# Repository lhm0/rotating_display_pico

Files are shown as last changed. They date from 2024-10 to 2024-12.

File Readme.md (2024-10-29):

# Rotating Display Pico

## Abstract: 
The Rotating Display Pico is a compact disc-sized device that rotates quietly using a CD motor. It features 56 white LEDs which are controlled by a raspberry pi pico. The device can display animated images as well as time and weather data sourced from the internet. It is wirelessly powered and controlled via a user-friendly web interface. The device uses off-the-shelf components and is easy to assemble in a DIY electronics project.
 
<p align="center"> 
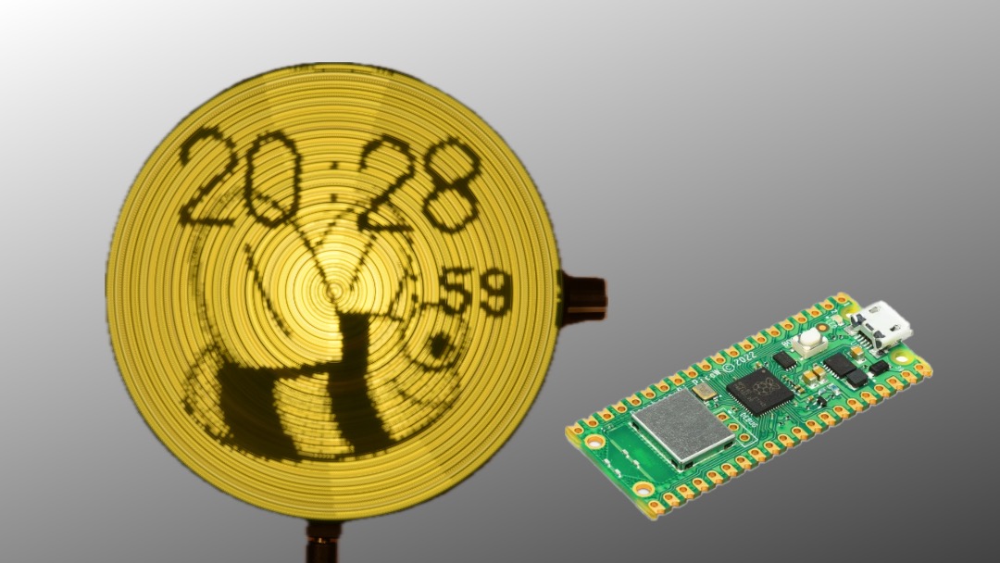
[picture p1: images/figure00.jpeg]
  
</p>

<p align="center"> 
<a href="https://youtu.be/Msv1gF6FXeg" target="_blank">
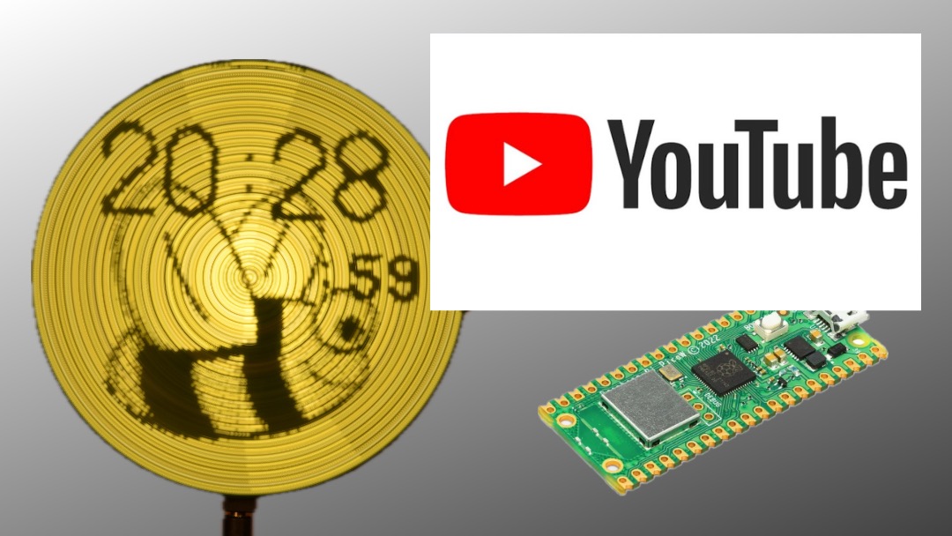
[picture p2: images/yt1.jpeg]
  
</a>
</p> 

## 1. Description of the device

The Rotating Display pico device comprises two primary units: a power supply unit and a display board (**figure 1**). Both are circular in design, with a diameter of 120mm, similar to the dimensions of a standard Compact Disk. The display board is rotated by a CD motor. Energy is wirelessly transmitted from the power supply unit to the display board, eliminating the need for wired connections.

<p align="center"> 
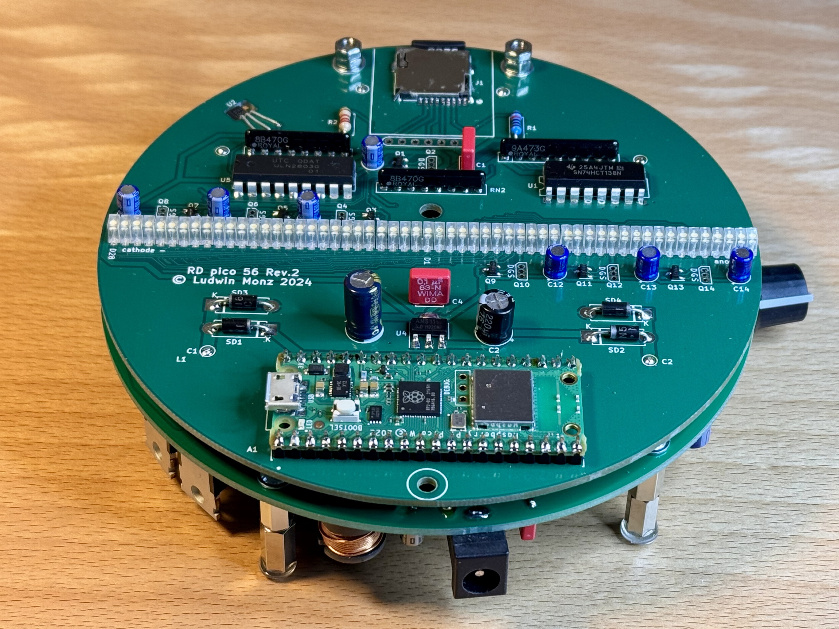
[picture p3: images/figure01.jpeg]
  
</p>

**Figure 1:  Rotating Display pico assembly.** The lower PCB is the power supply with wireless power transmission, the upper PCB is the display board.

The display board is equipped with a row containing 56 white LEDs. The LED operations are controlled by a Raspberry Pi Pico W, which at the same time generates the display content, maintains a Wi-Fi connection to the internet, and provides a web user interface. Images (including animated images) can be stored on and loaded from a micro SMD card. 

This internet connection allows the device to retrieve the time from a time server, ensuring time accuracy. It also allows for the acquisition of weather data. Device operation is managed through a web interface (**figure 2**), accessible from any web browser. The interface allows users to manage login credentials, upload image files to the display, and control image and configuration files through a file manager.

<p align="center"> 
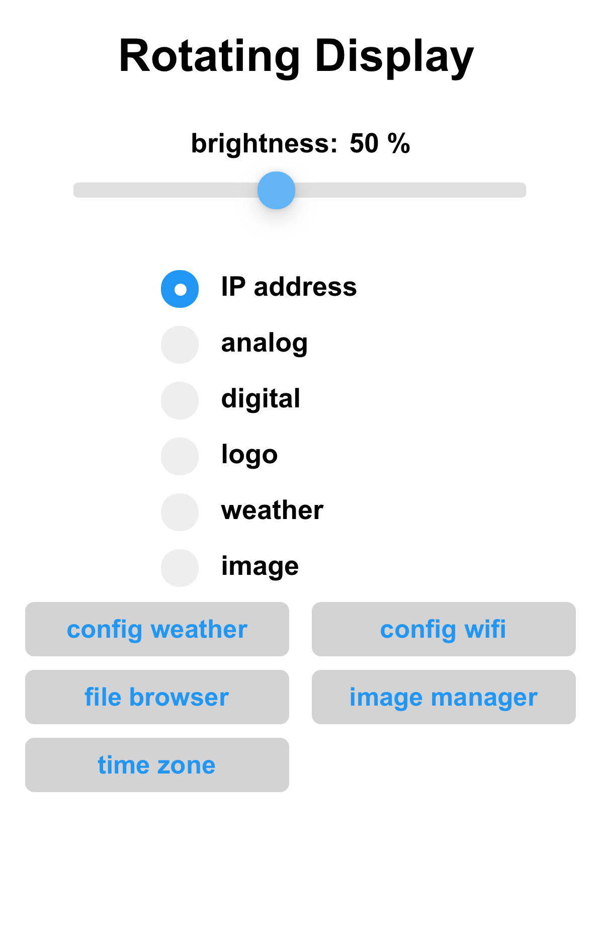
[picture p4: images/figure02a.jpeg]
  
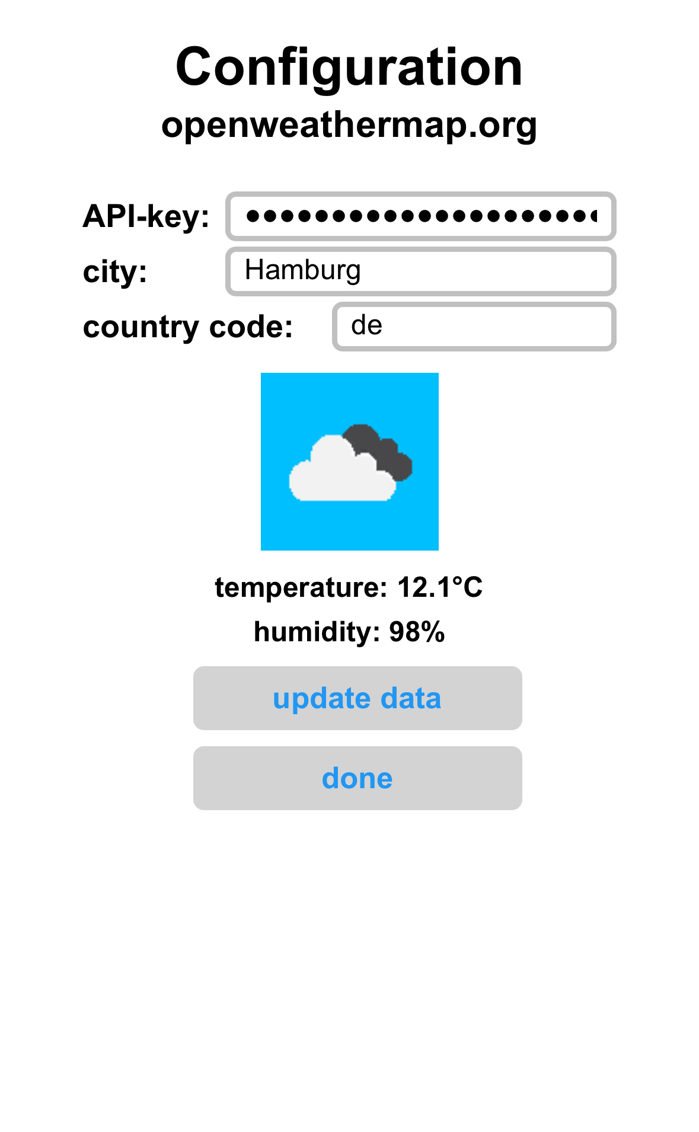
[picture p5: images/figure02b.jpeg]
  
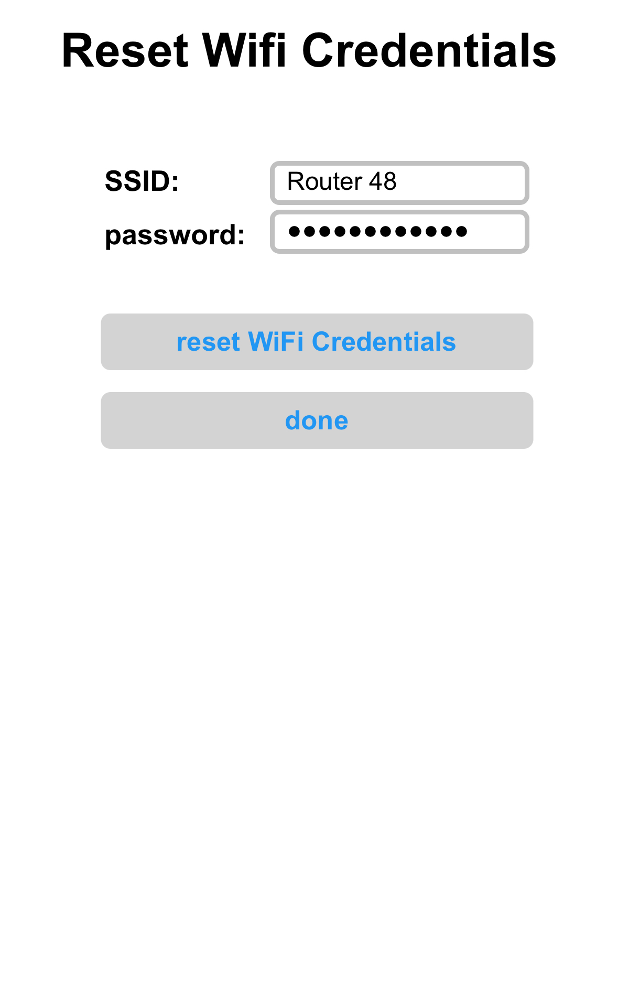
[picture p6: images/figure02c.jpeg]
  
</p>
<p align="center"> 
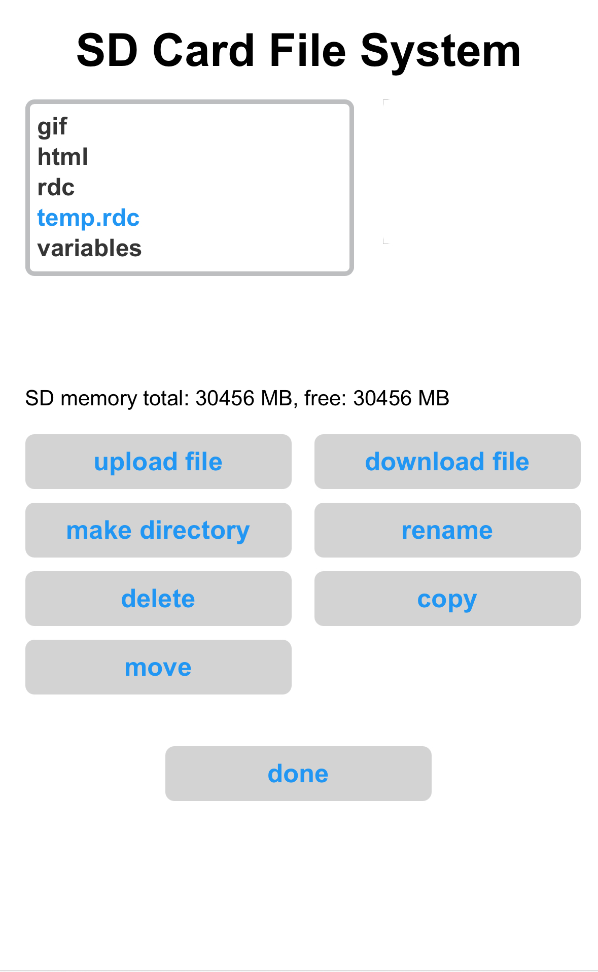
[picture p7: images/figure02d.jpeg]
  
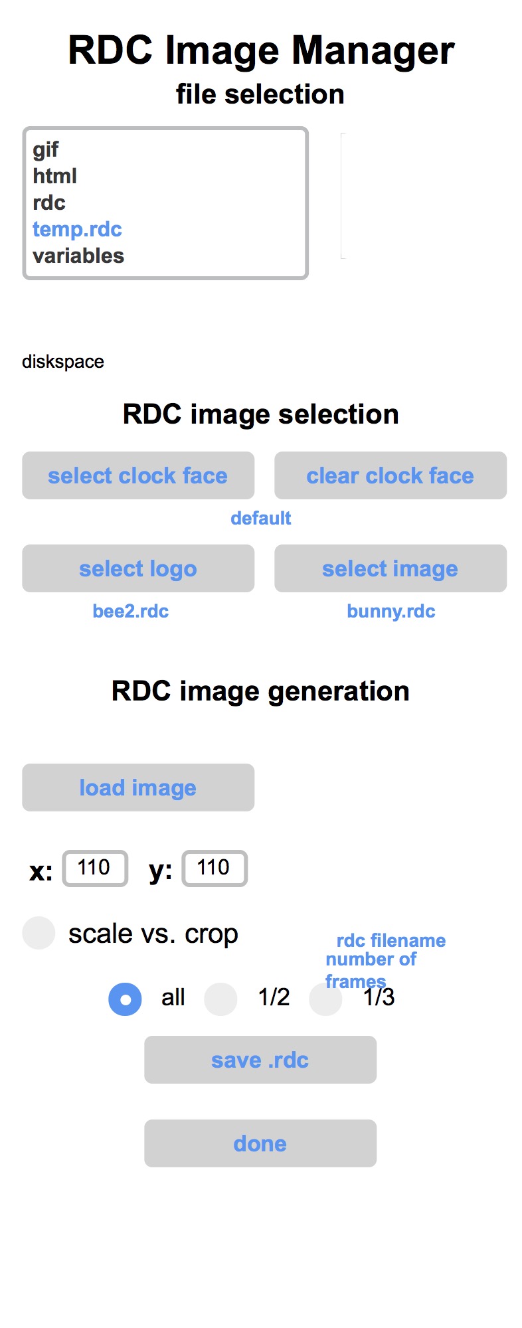
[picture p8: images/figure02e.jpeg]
  
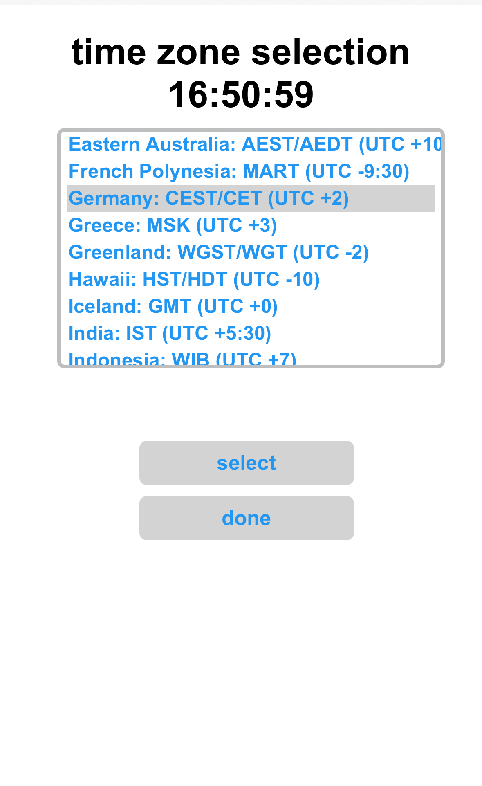
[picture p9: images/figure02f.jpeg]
  
</p>

**Figure 2:** The **web user interface** allows for operating mode selection and device configuration.

## 2. Operating modes

When switched on, the device tries to connect to a known wifi. If no valid wifi credentials are found, the unit will be configured as wifi access point. In this mode, a computer or mobile device can be connected, directly (SSID: RD56m, no password). 

Once the wifi connection has been established, the unit will display its IP address on the  home page of the device (**figure 3**). Enter this address in your web browser. This will load the web user interface and will allow you to configure your local wifi.

<p align="center"> 
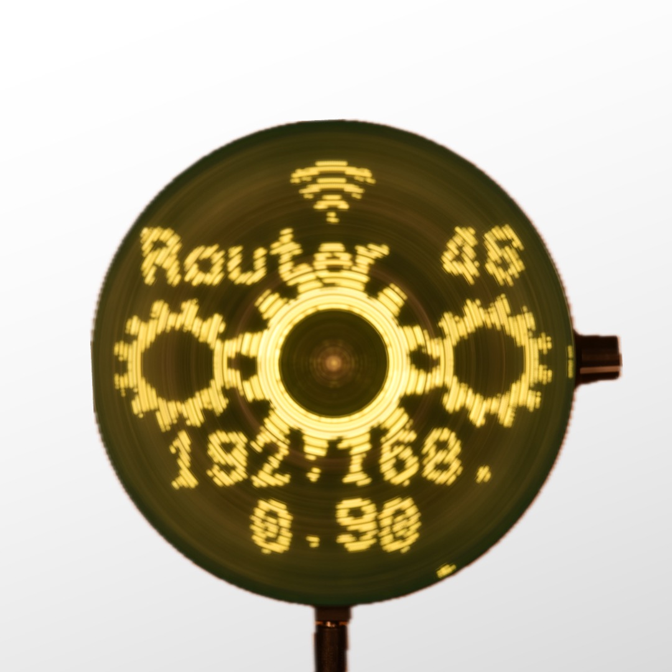
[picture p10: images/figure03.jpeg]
  
</p>

**Figure 3: home page.**

There are several operating modes that display time and weather information (**figure 4**). The logo clock mode integrates a customizable image into the clock face. The image can be easily uploaded from the user interface. The same is true for the analog clock, which uses a customizable clock face in the background.

<p align="center"> 
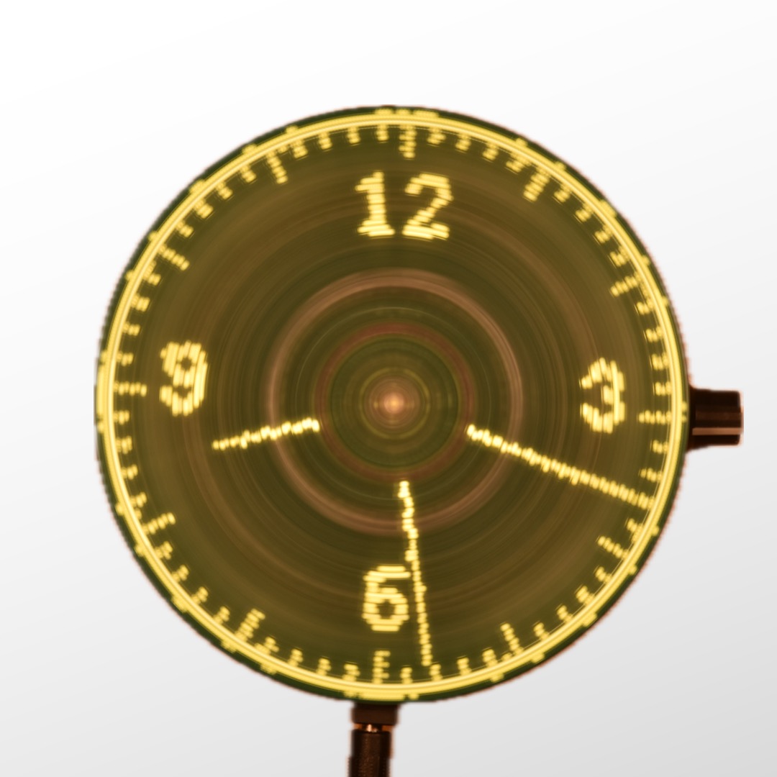
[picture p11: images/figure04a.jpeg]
  
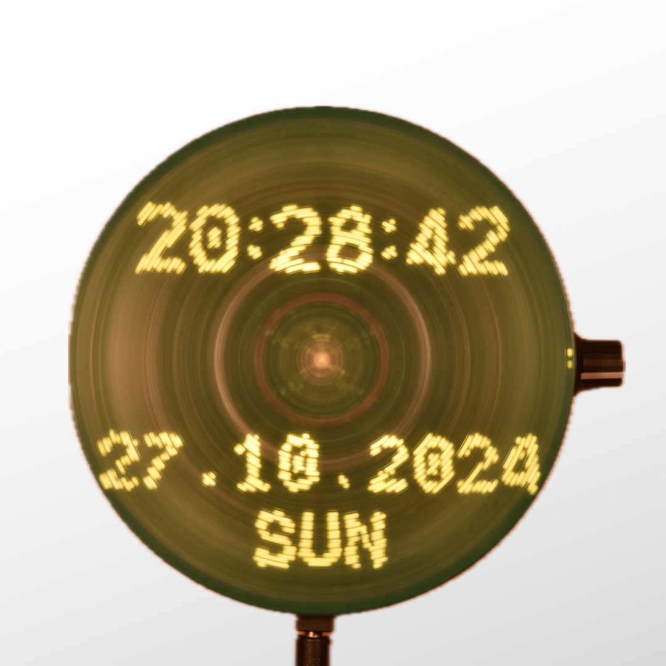
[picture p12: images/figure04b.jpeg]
  
</p>
<p align="center"> 
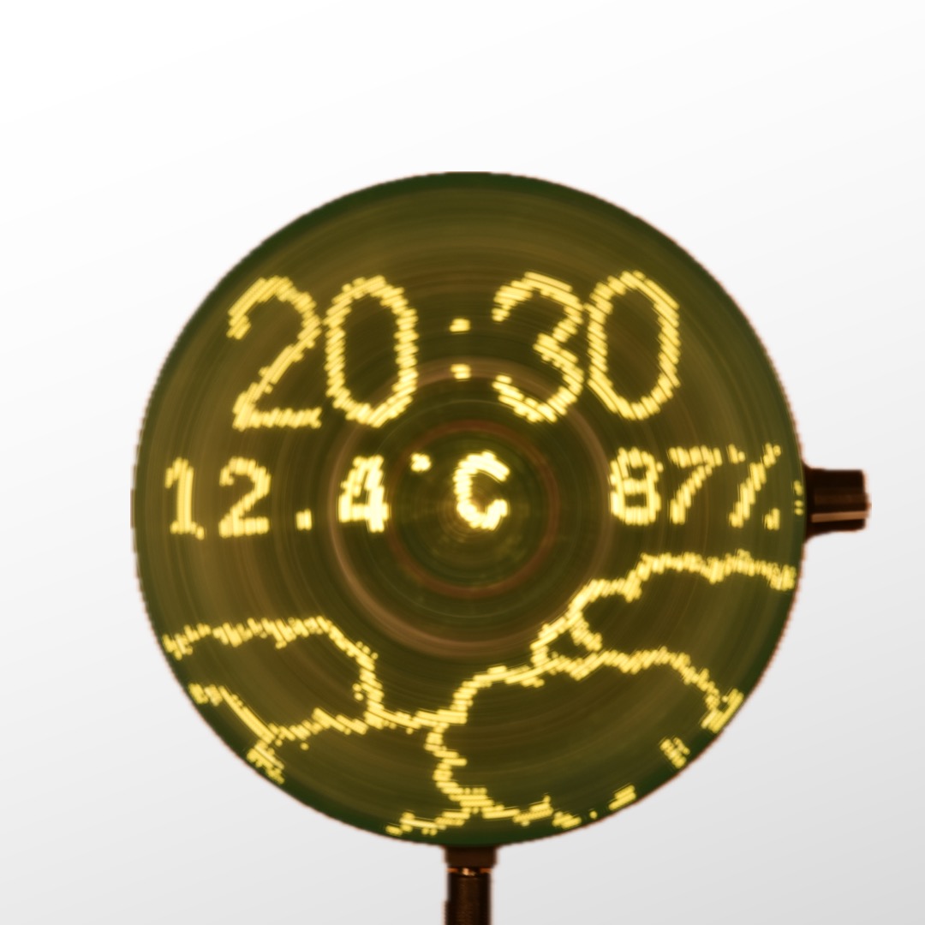
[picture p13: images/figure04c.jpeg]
  
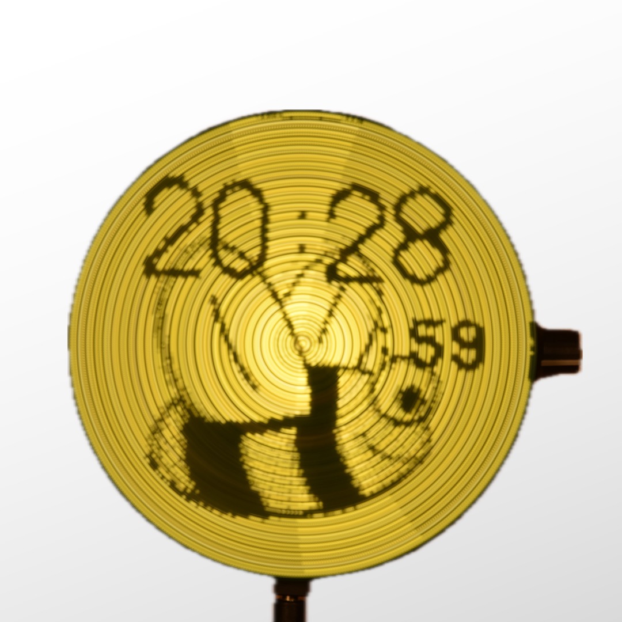
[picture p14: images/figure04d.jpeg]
  
</p>
<p align="center"> 
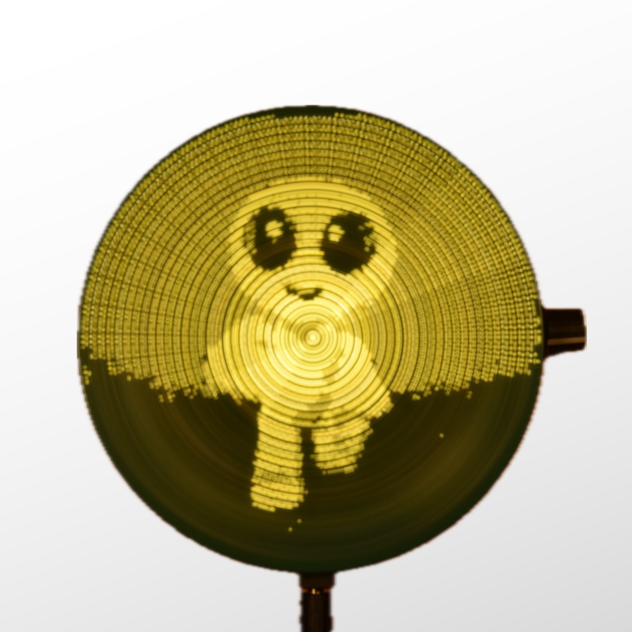
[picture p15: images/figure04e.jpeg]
  
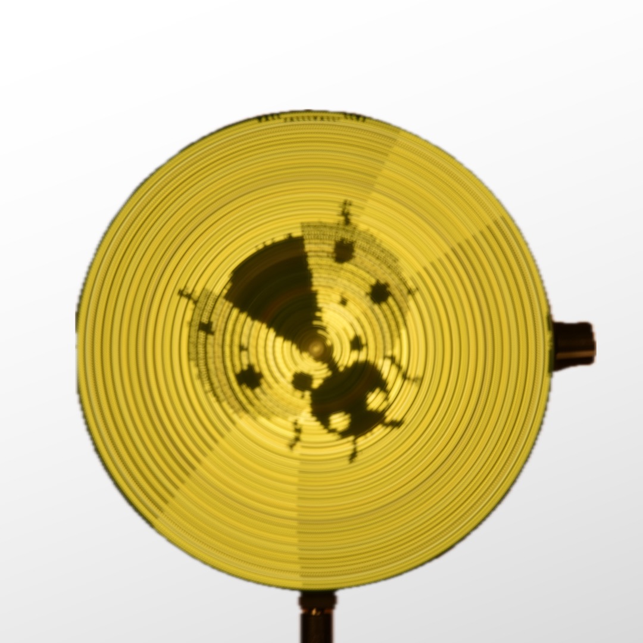
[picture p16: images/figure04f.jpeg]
  
</p>

**Figure 4: operating modes.** Modes can be selected and configured through the web interface.

## 3. Mechanical design

The device consists of two assemblies: power supply and display. The power supply board is also the base plate, which can either be placed on a flat surface or hung on a wall. A standard CD motor is attached to this board so that the CD tray above the power supply board can accommodate the display assembly. The display board is fixed with two M2 x 6 mm screws. Furthermore, the base plate carries a potentiometer to control the motor speed as well as an on/off switch for the motor.

<p align="center"> 
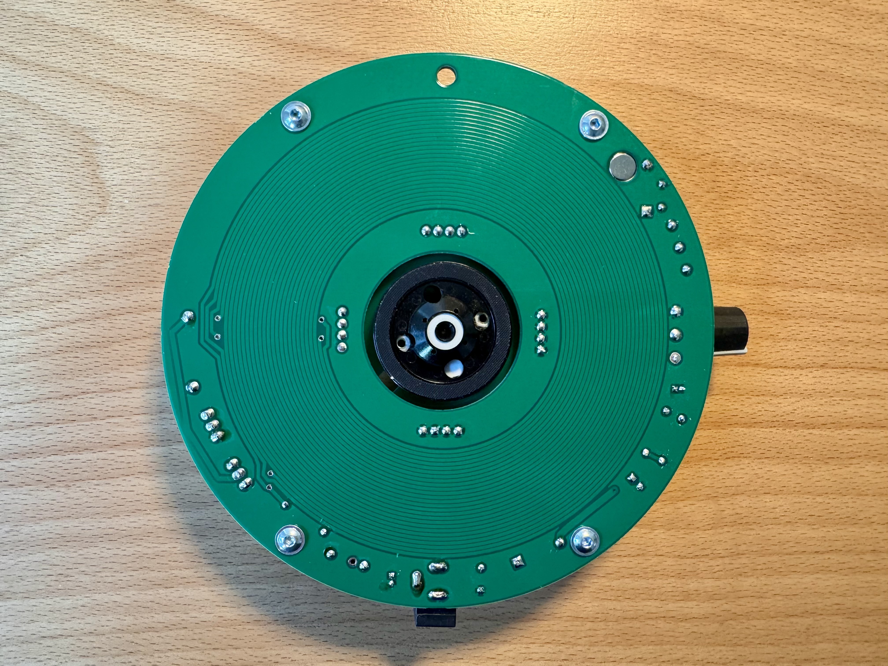
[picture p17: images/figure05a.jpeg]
  
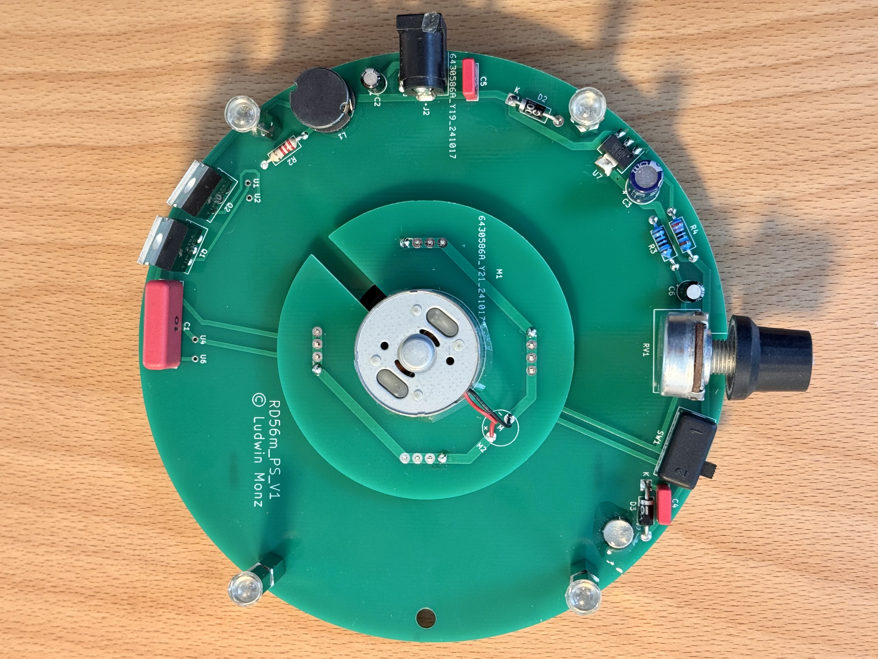
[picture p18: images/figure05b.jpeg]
  
</p>

**Figure 5: Power Supply Board** with CD motor (middle), 12 V power jack (lower side), and speed potentiometer

An important requirement for the display board is that the center of mass of the unit is exactly in the middle, on the axis of rotation of the motor. This is the only way to ensure smooth and vibration-free running of the display. To achieve this, the electronic components are arranged symmetrically to the vertical axis of symmetry (**figure 7**). This initially ensures that the center of gravity lies on this vertical axis. However, since the components cannot be distributed symmetrically to the horizontal axis of symmetry, the center of gravity must be shifted to the center along this axis using balancing weights. For this purpose, two M3x6mm screws with two nuts each are placed to the right and left of the micro SD card slot. The overall balancing result is very good, but can certainly be further optimized.

<p align="center"> 
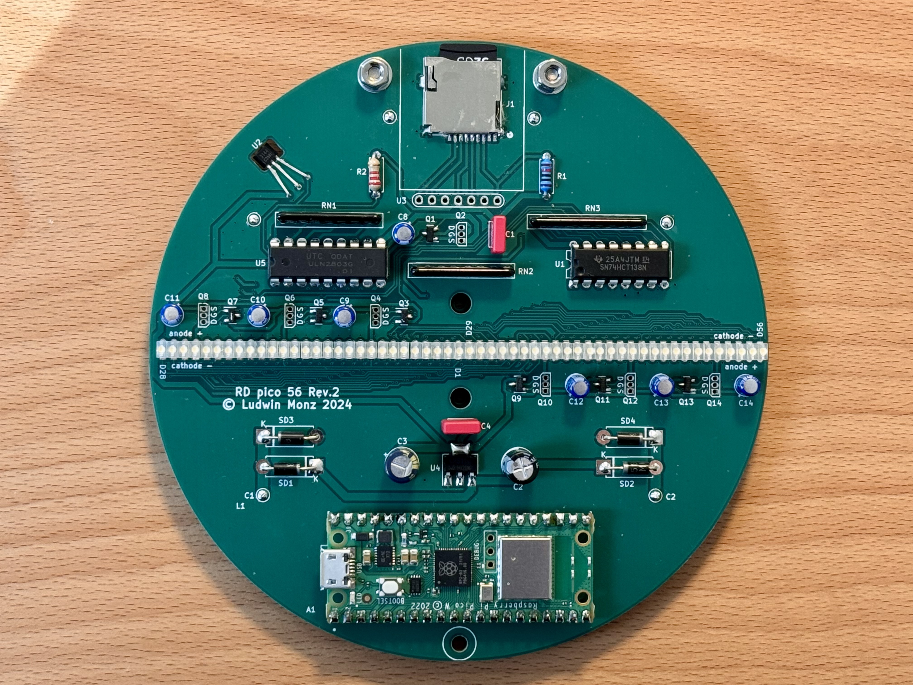
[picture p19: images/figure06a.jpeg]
  
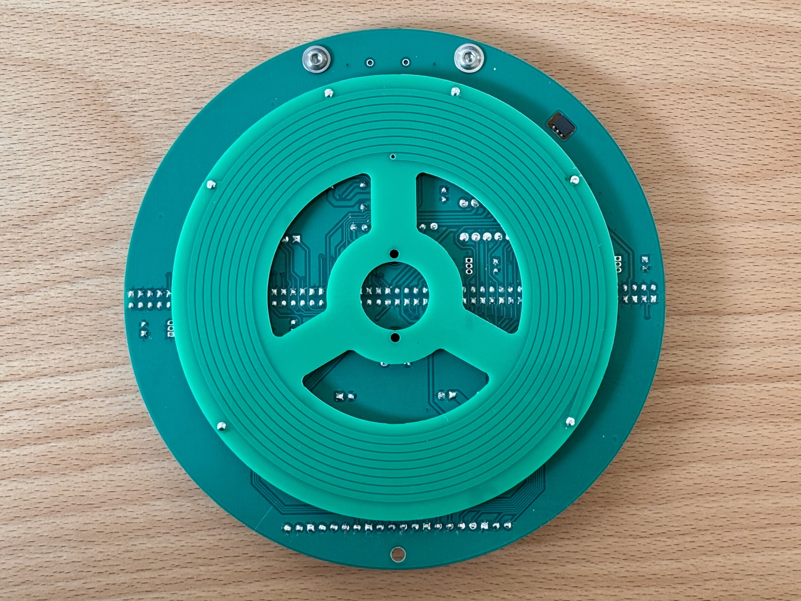
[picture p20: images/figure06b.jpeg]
  
</p>

**Figure 6: Display Board.** Main components are the LED row, the Raspberry Pi Pico W microcontroller, and two driver chips for the LEDs. On the backside of the board the secondary coil of the wireless power supply is attached.

<p align="center"> 
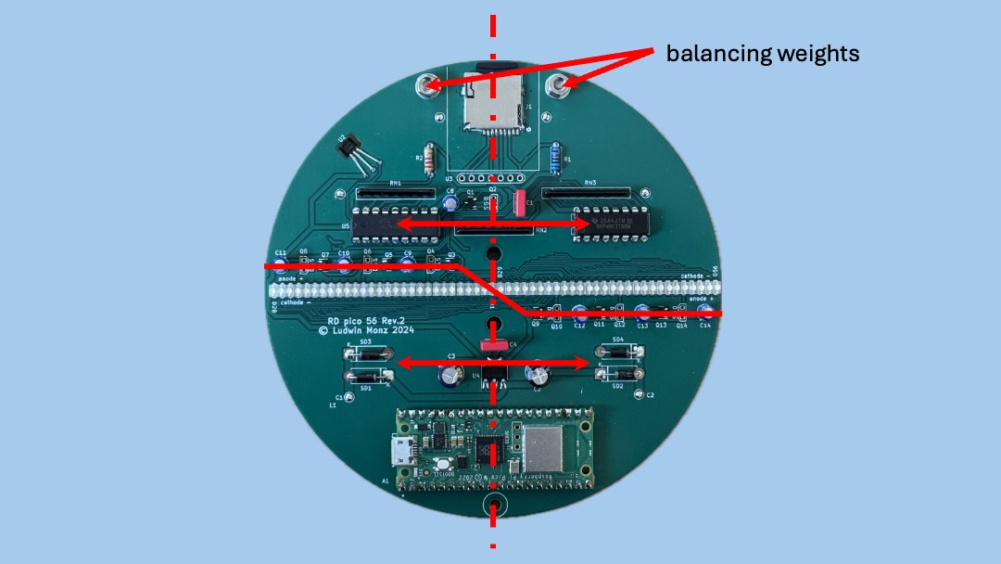
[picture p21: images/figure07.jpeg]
  
</p>

**Figure 7:** The components of the display board are arranged symmetrically to the vertical axis of symmetry. Balancing weights are used to shift the center of gravity to the middle of the disk.

The LED row consists of 56 discrete, rectangular LEDs. The components each have a width of 2.0 mm and can be lined up with little spacing. However, the row of LEDs is not arranged symmetrically to the center of the disk, but shifted by 0.5 mm. If the display panel is rotated by 180 degrees, this decentration causes the LEDs to be shifted by exactly 1 mm from the original grid (**figure 8**). This results in rotational interlacing: the radial resolution is increased from 2 to 1 mm. At the same time, the perceived frame rate also increases by a factor of 2..

<p align="center"> 
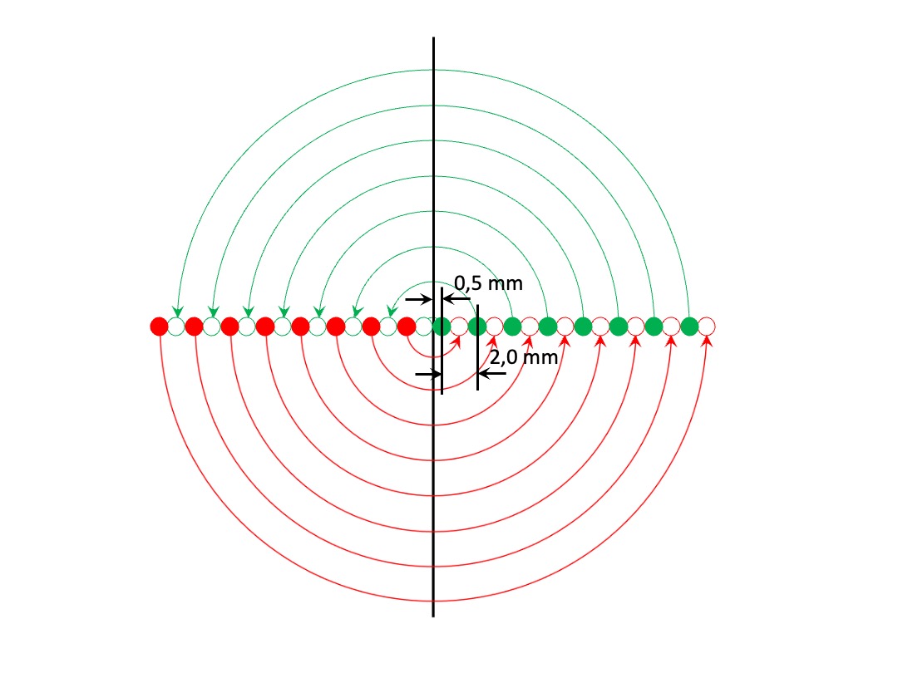
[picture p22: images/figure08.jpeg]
  
</p>

**Figure 8:** The LED row is shifted radially by half a LED width. The two halfs of the row generate an interlacing effect, which doubles both the radial resolution and the image frame rate.

The LEDs must output the image information at exactly the right position with each rotation. For spatial alignment of the image, a trigger signal is generated at a defined position for each rotation, which triggers the sequential, clocked output of the pixels. The trigger signal must be spatially very stable, otherwise no smooth image can be generated. It turned out that a Hall sensor is best suited for this purpose. It is located on the left-hand side of the disk at the 10:30 clock position (see **figure 6**, left picture). The magnet is glued into a hole of the power supply PCB (see figure 5, left picture, 2 o'clock position).

## 4. Electronics architecture

The distribution of the electronic circuitry between the two assemblies is shown in **figure 9**. The power supply assembly contains a Royer converter for wireless power transfer to the display assembly and an adjustment of the motor speed. The 56 LEDs of the display assembly are arranged in a matrix and are multiplexed by the microcontroller. The displayed content is either loaded from the internet via Wifi (time, weather data) or generated from image data locally, which is stored on a micro SD card.

<p align="center"> 
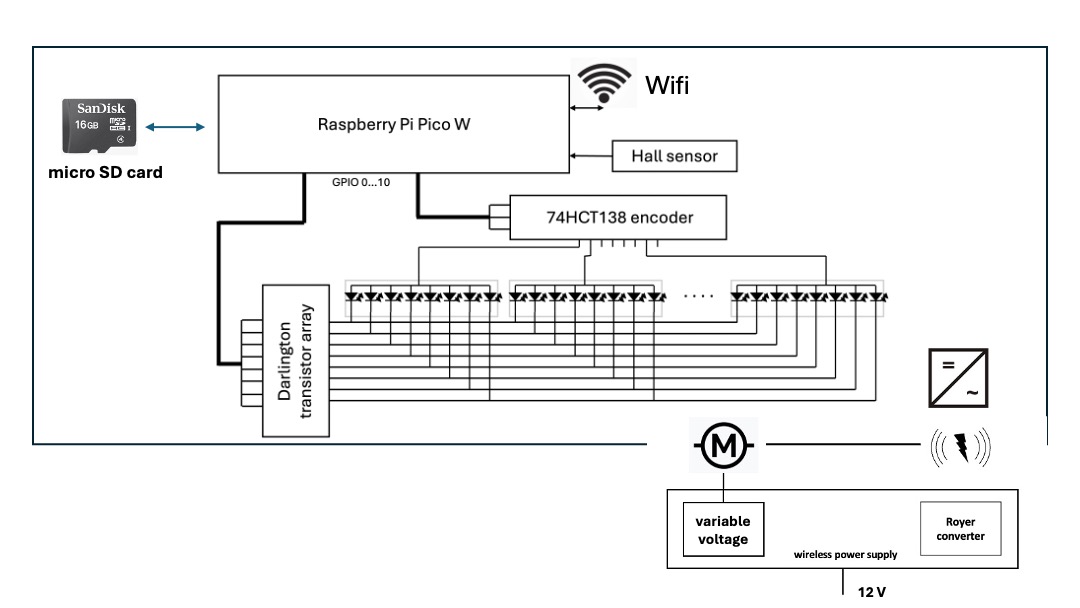
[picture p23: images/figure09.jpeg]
  
</p>

## 5. Power supply board

The core of the power supply is a Royer converter for wireless power transfer. An excellent article on the operation and design of the circuit can be found at [Mikrocontroller.net](https://www.mikrocontroller.net/articles/Royer_Converter) (German) and the circuit was taken from there. Two transistors are alternately switched (push pull operation) so that a current flows through one half of the coil at a time. The coil belongs to a resonant circuit with a resonant frequency of about 120 kHz. The control voltage for the transistors is obtained via a coupling coil (**figure 10**). The secondary coil is located below the display board (see **figure 6**, right).

The Royer circuit uses very few components. However, the coil is quite complex. It is a bifilar coil, where the two halves are interleaved. In addition, the coupling coil must be connected with the correct polarity, otherwise the two transistors will be destroyed. In the early stages of development, the coil was wound with copper wire. However, this solution was quite difficult to reproduce, so in the final design the coils (bifilar primary coil, coupling coil, secondary coil) were implemented as a printed circuit (see **figure 5**, left and **figure 6** right). The circuit was found to have surprisingly high and perfectly adequate transmission efficiency, although the quality factor of the printed coils is inevitably compromised. The Royer converter with the printed coil assembly is absolutely safe to rebuild. It is supplied with 12 V. 

<p align="center"> 
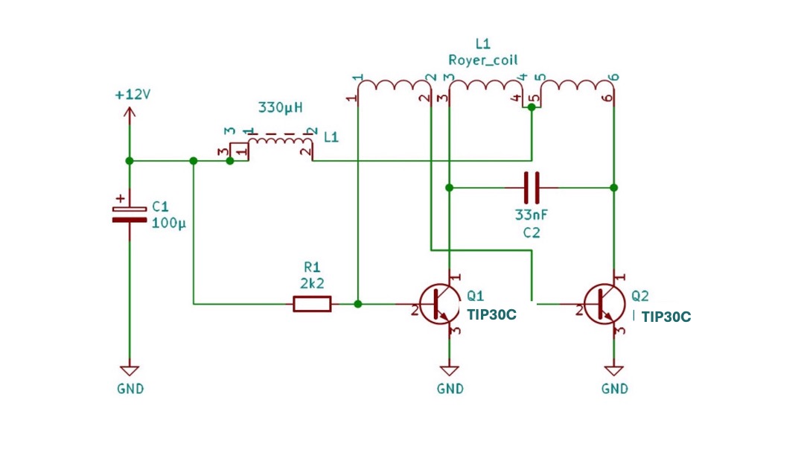
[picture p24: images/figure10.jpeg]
  
</p>

**Figure 10: Royer converter**. Compare [Mikrocontroller.net](https://www.mikrocontroller.net/articles/Royer_Converter) for reference.

There is also a circuit for supplying the CD motor on the power supply board. By means of an adjustable voltage regulator, a variable voltage between 1.7V and 6.0V is generated. It can be adjusted via a potentiometer. The voltage range corresponds to the specified operating range of the CD motor. The supply of the motor can be interrupted with a switch, for example to allow programming of the microcontrollers.

## 6. Display Board
The 56 LEDs of the display are arranged in a matrix with 7 columns and 8 rows (**figure 11**). The microcontroller activates the columns successively and sets the rows for each columns as needed.

The columns are activated by connecting them to +5V by means of a p-channel MOSFET, each. The control of the MOSFETs needs 5V logic (+5V = off, 0V = on), while the Raspberry pi pico operates with 3.3V logic. Therefore, levels need to be shifted, which is done with the 74HCT138. The circuit is a 3 bit decoder. One of the 8 outputs can be selected by setting the 3 inputs accordingly. Only the selected output goes to "L", while all other outputs are "H". This ensures, that only one LED column can be selected at a time.

The 8 rows are activated by means of a Darlington transistor each. The transistors are arraged in an array (ULN2803). The resistors set the LED current to about 60 mA. This is well with the [specification of the LEDs](https://www.led1.de/shop/files/Datenblaetter/Rechteckig/WEHWW02-D1M.pdf).

<p align="center"> 
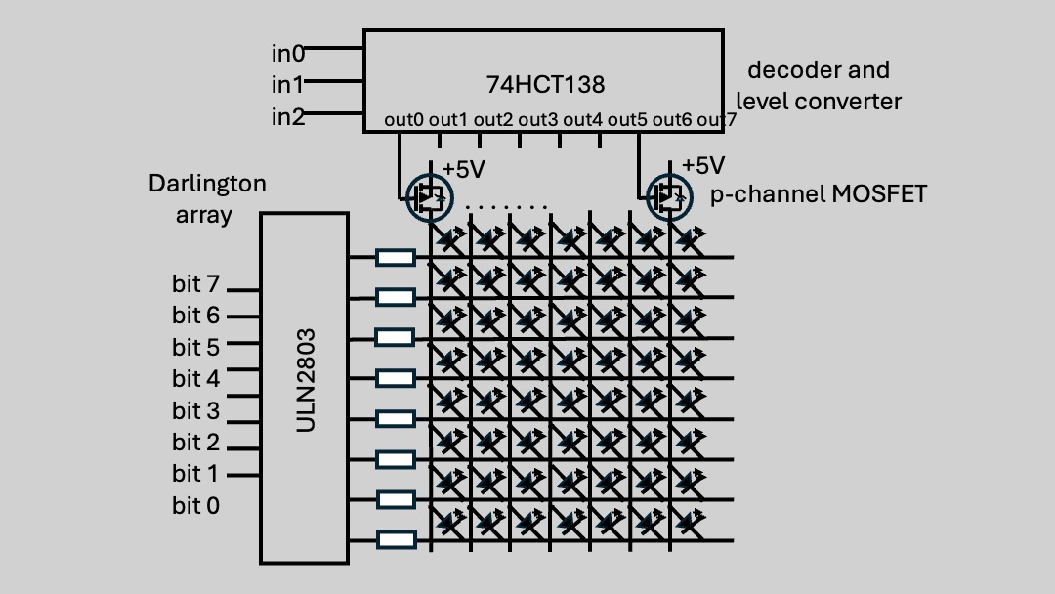
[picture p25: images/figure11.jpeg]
  
</p>

**Figure 11: Schematic of the Display Board**

The timing of the display is critical in order to generate stable largely flicker free grey level images. **Figure 12** shows the timing sequence. The display rotates with a frequency of up to 10 Hz. The Hall sensor generates a reference signal once it is within reach of the static magnet. Within the 100 ms per revolution, 240 lines with 56 pixels each are successively displayed. Each line will be displayed for 100ms/240 = 420µs. In order to generate grey levels, each pixel is split into 8 "sub pixels". If all of the subpixels are "on", the intensity of the pixel will be maximal, if 4 subpixels are "on" and 4 subpixels are "off", intensity of the pixel will be medium, and if all subpixels are "off", intensity will be zero. The time per subpixel is 420µs/8 = 52µs. Within this time, the multiplexing of the LEDs has to happen. Each column of the matrix will be displayed for 52µs/7 = 7.5µs. 

<p align="center"> 
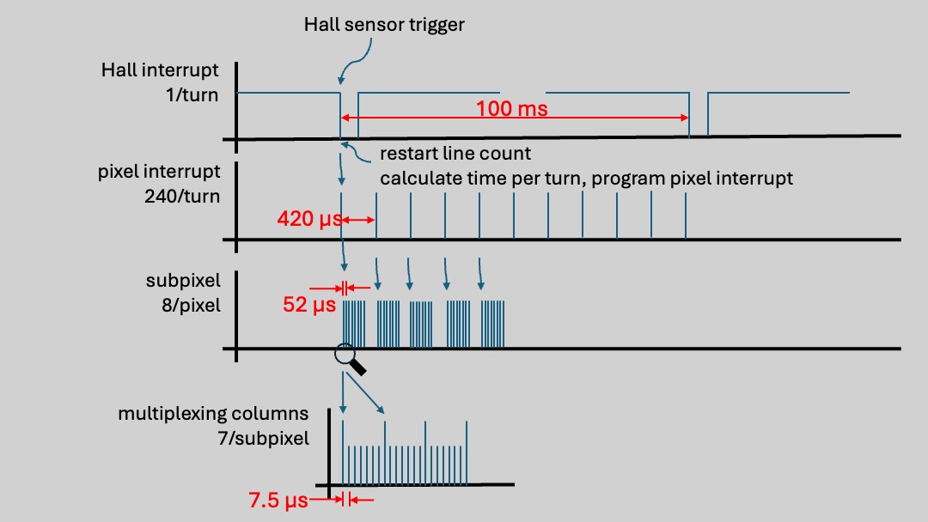
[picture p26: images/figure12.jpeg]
  
</p>

**Figure 12: Timing of the LED control.** Within the time per revolution of 100ms, 240 lines with 8 grey levels are displayed. 

The high speed of the multiplexing has quite some implications. The electronics and its setup needs to allow for very short and steep 60 mA current pulses. In order to manage electromagnetic interference, a 4 layer board has been used. The two inner layers are grounding planes, all vias have a grounding "companion", in order to ensure [proper current return paths](https://www.youtube.com/live/ySuUZEjARPY?si=sn-svxhxvuI3ehGK). Furthermore, the microcontroller needs to control the output lines in a strict and very fast time regime.

Fortunately, the RP2040 microcontroller has a powerful unit for controlling the input and outputs (PIO = programmable IO) (**figure 13**). This unit is used to manage the multiplexing and decouple its timing from the processor and its interrupts as much as possible. The solution ensures not only the necessary very high speed for the multiplexing, but also generates a stable time regime.

<p align="center"> 
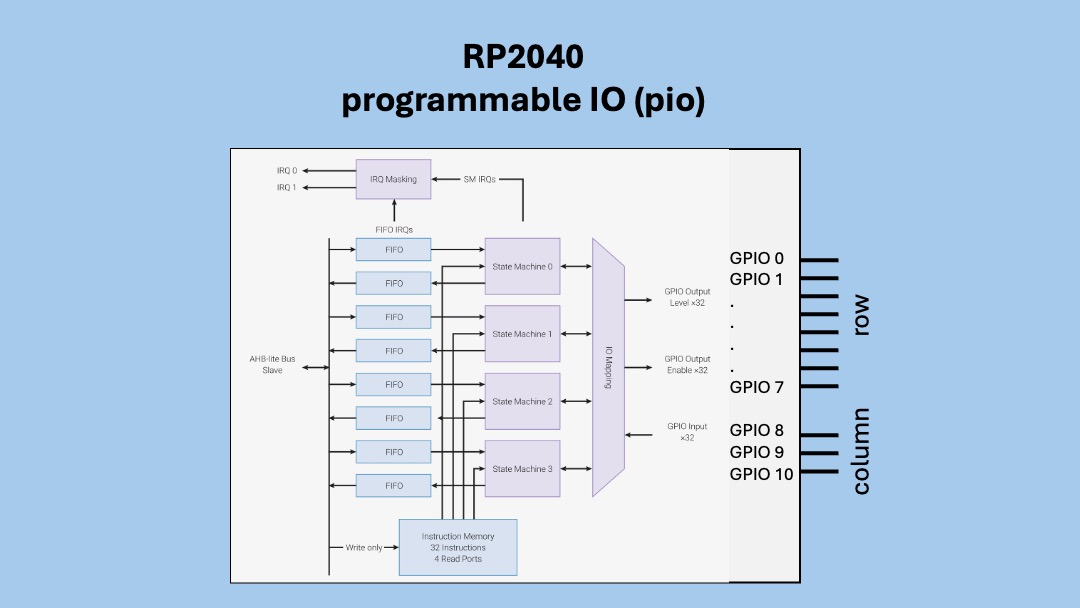
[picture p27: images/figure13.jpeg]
  
</p>

**Figure 13: RP2040 programmable IO (PIO).** The unit allows for fast multiplexing of the LEDs. 

The full circuit diagram of the display board is shown in **figure 14**. All details can be obtained from the [GitHub repository](https://github.com/lhm0/rotating_display_pico/tree/master).

<p align="center"> 
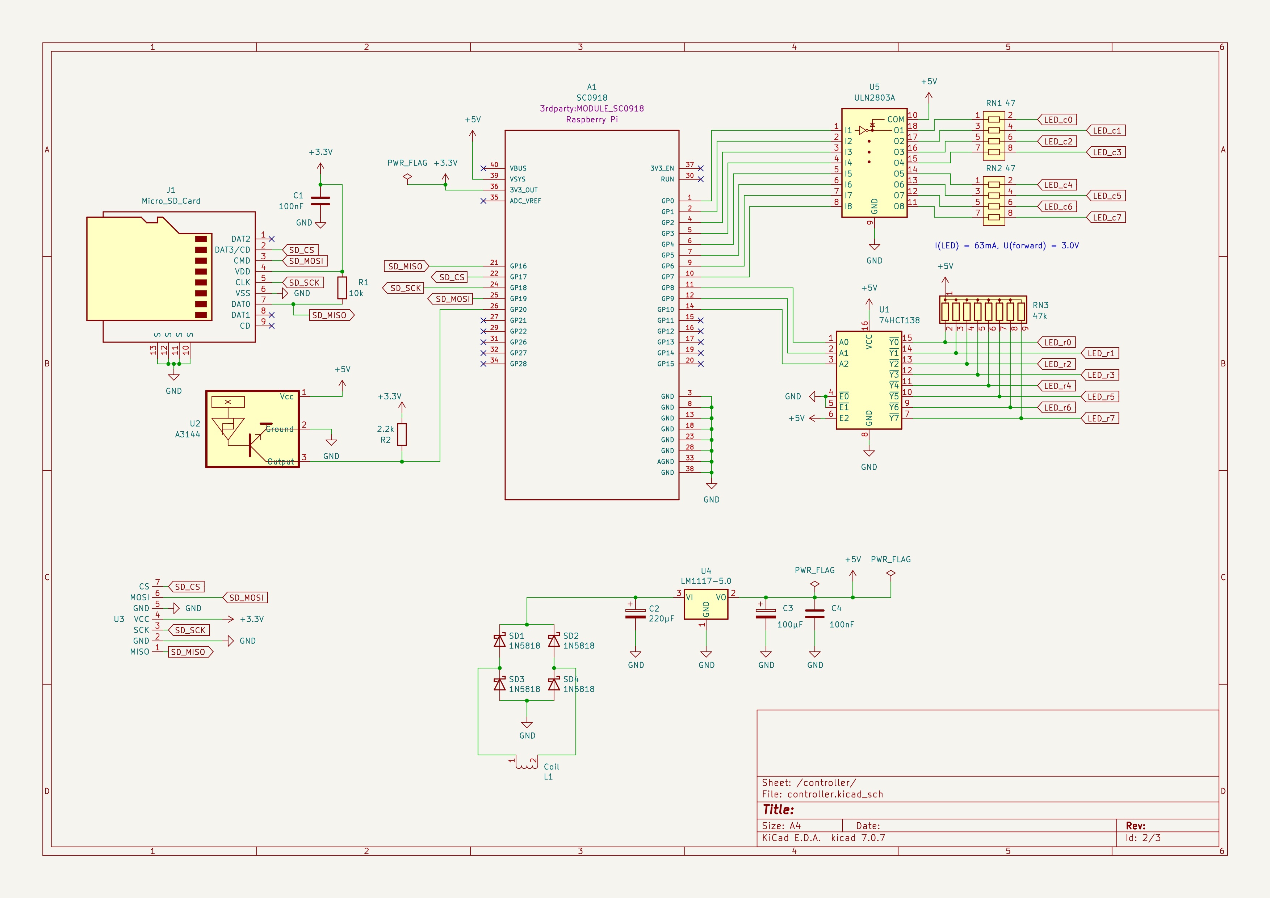
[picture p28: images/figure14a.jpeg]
  
</p>

<p align="center"> 
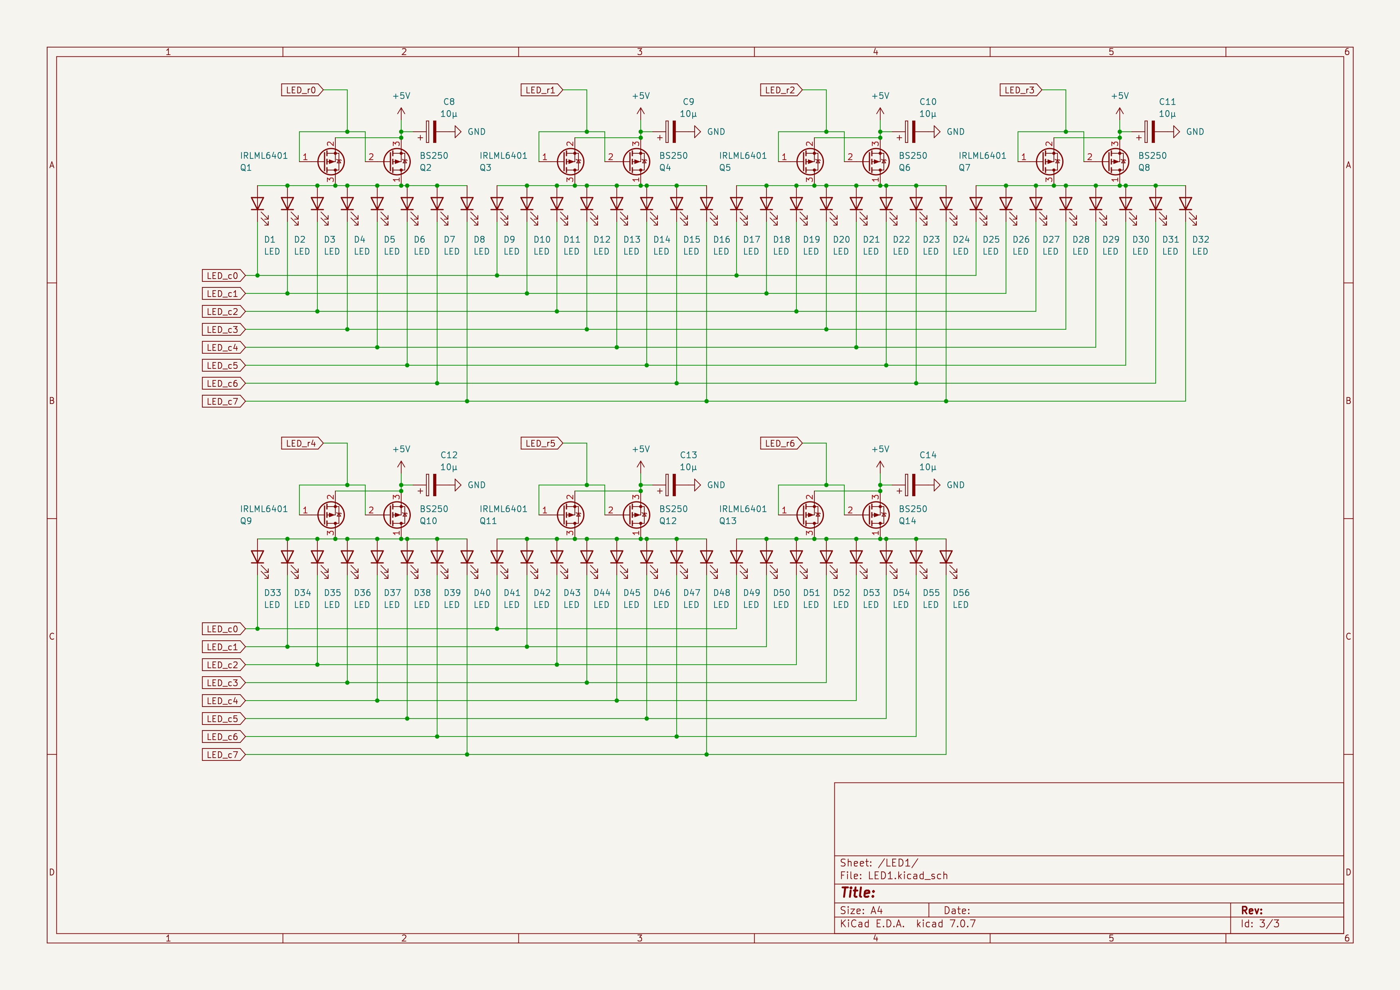
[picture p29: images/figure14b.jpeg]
  
</p>

**Figure 14: Circuit diagram of the display board**

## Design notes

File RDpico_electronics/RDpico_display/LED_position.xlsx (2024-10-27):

No. | radialer Absrand zum Zenith | theta | theta (Grad) | x | y |  |  |  |  |  | r
63 | 0.525 | 0.00875 | 0.5013380707 | -0.51 | -58.50 | -89.50 |  |  |  |  | 58.5 | 44 | 49.4 | 56.6
62 | 2.625 | 0.04375 | 2.506690354 | -2.56 | -58.44 | -87.49
61 | 4.725 | 0.07875 | 4.512042637 | -4.60 | -58.32 | -85.49
60 | 6.825 | 0.11375 | 6.51739492 | -6.64 | -58.12 | -83.48
59 | 8.925 | 0.14875 | 8.522747203 | -8.67 | -57.85 | -81.48 | -9.63 | -57.70
58 | 11.025 | 0.18375 | 10.52809949 | -10.69 | -57.52 | -79.47 | -9.32 | -55.83
57 | 13.125 | 0.21875 | 12.53345177 | -12.70 | -57.11 | -77.47
56 | 15.225 | 0.25375 | 14.53880405 | -14.69 | -56.63 | -75.46 |  |  | 0.09625 | -4.23 | -43.80 | 5.514718778 | 0.3661465543 | 3.792365581
55 | 17.325 | 0.28875 | 16.54415633 | -16.66 | -56.08 | -73.46 |  |  |  | -8.02 | -43.43 | 5.514718778 | R | 8.02 | -43.43 | 5.514718778
54 | 19.425 | 0.32375 | 18.54950862 | -18.61 | -55.46 | -71.45 |  |  | 0.16625 | -8.51 | -50.69 | -80.47457666 | C | 8.51 | -50.69 | -80.47457666
53 | 21.525 | 0.35875 | 20.5548609 | -20.54 | -54.78 | -69.45 |  |  | 0.20125 | -8.63 | -48.66 | -168.4692244 | Q | 8.63 | -48.66 | -11.53077563
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

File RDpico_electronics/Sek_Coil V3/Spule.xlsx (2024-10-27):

 | M | M | S | S | R | E | alpha | x | y
1 | 0 | 0.45 | 0 | 46 | 45.55 | -45.1 | 65 | 41.2823197 | 19.70026182
1 |  | -0.45 |  | -45.1 | -44.65 | 44.2
2 |  | 0.45 |  | 44.2 | 43.75 | -43.3
2 |  | -0.45 |  | -43.3 | -42.85 | 42.4
3 |  | 0.45 |  | 42.4 | 41.95 | -41.5
3 |  | -0.45 |  | -41.5 | -41.05 | 40.6
4 |  | 0.45 |  | 40.6 | 40.15 | -39.7
4 |  | -0.45 |  | -39.7 | -39.25 | 38.8
5 |  | 0.45 |  | 38.8 | 38.35 | -37.9
5 |  | -0.45 |  | -37.9 | -37.45 | 37
6 |  | 0.45 |  | 37 | 36.55 | -36.1
6 |  | -0.45 |  | -36.1 | -35.65 | 35.2
7 |  | 0.45 |  | 35.2 | 34.75 | -34.3
7 |  | -0.45 |  | -34.3 | -33.85 | 33.4
8 |  | 0.45 |  | 33.4 | 32.95 | -32.5
8 |  | -0.45 |  | -32.5 | -32.05 | 31.6
9 |  | 0.45 |  | 31.6 | 31.15 | -30.7
9 |  | -0.45 |  | -30.7 | -30.25 | 29.8
10 |  | 0.45 |  | 29.8 | 29.35 | -28.9
10 |  | -0.45 |  | -28.9 | -28.45 | 28
11 |  | 0.45 |  | 28 | 27.55 | -27.1
11 |  | -0.45 |  | -27.1 | -26.65 | 26.2
 |  | 0.45 |  | 26.2 | 25.75 | -25.3
 |  | -0.45 |  | -25.3 | -24.85 | 24.4
 |  | 0.45 |  | 24.4 | 23.95 | -23.5
 |  | -0.45 |  | -23.5 | -23.05 | 22.6
 |  | 0.45 |  | 22.6 | 22.15 | -21.7
 |  | -0.45 |  | -21.7 | -21.25 | 20.8

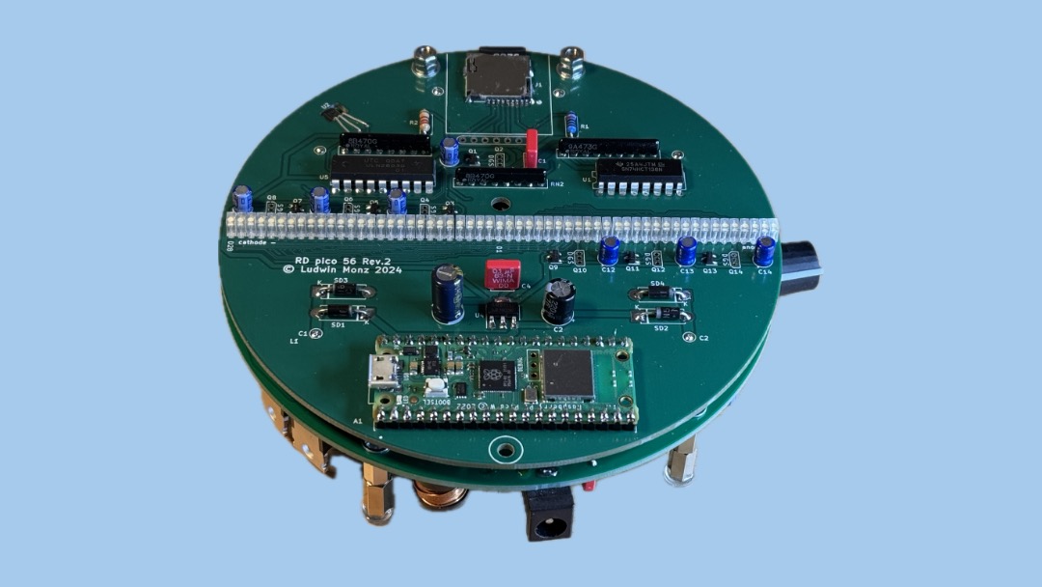
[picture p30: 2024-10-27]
images/page5.jpg

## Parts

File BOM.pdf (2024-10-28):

# BOM Rotating Display Pico

## 1. RDpico_display

# Reference | Qty Description | source

1 A1 | 1 Raspberry Pi Pico W | https://www.raspberrypi.com/products/raspberry-pi-pico/
2 C1, C4 | 2 100nF, | https://www.digikey.com/short/2bw9dzmp
3 C2 | 1 220µF | https://www.digikey.com/short/hrdj5tbz
4 C3 | 1 100µF | https://www.digikey.com/short/mfjrnd3m

5

C8, C9, C10, C11, C12,
C13, C14 | 7 10µ | https://www.digikey.com/short/zchpnfr9

6

D1, D2, D3, D4, D5,
D6, D7, D8, D9, D10,
D11, D12, D13, D14,
D15, D16, D17, D18,
D19, D20, D21, D22,
D23, D24, D25, D26,
D27, D28, D29, D30,
D31, D32, D33, D34,
D35, D36, D37, D38,
D39, D40, D41, D42,
D43, D44, D45, D46,
D47, D48, D49, D50,
D51, D52, D53, D54,
D55, D56 | 56 LED | https://www.led1.de/shop/standard-leds/led-rechteckig-ultrahell/led-rechteckig-3x2-warmweiss-diffus-1800mcd-wehww02-d1m.html
7 J1 | 1 Micro_SD_Card Slot | https://www.digikey.com/short/5tpr3ntn

9

Q1, Q3, Q5, Q7, Q9,
Q11, Q13 | 7 IRLML6401 | https://www.digikey.com/short/mmb8j7pn

10

Q2, Q4, Q6, Q8, Q10,
Q12, Q14 | 7 BS250 | https://www.digikey.com/short/m88p5n9d
11 R1 | 1 10k | generic
12 R2 | 1 2.2k | generic
13 RN1, RN2 | 2 47 Ohm | https://www.digikey.com/short/ddr9td25
14 RN3 | 1 47k | https://www.digikey.com/short/2vwz5frm
15 SD1, SD2, SD3, SD4 | 4 1N5818 | generic
16 U1 | 1 74HCT138 | https://www.digikey.com/short/bbtft5nn
17 U2 | 1 A3144 | Amazon
19 U4 | 1 LM1117-5.0 | https://www.digikey.com/short/zrwjc997
20 U5 | 1 ULN2803A | https://www.digikey.com/short/pjrb5nj3

## 2. RDpico_PS

# Reference | Qty Value | Footprint

1 C1 | 1 33nF | https://www.reichelt.de/mkp10-pp-puls-kondensator-33-nf-10-630-vdc-rm-15-mkp10-630-33n-p31975.html?&nbc=1
2 C2 | 1 10 µF, 50V | https://www.digikey.com/short/mcj02zrf
3 C3 | 1 100 µF | https://www.digikey.com/short/m1qfmmt3
4 C4, C5 | 2 100 nF | https://www.digikey.com/short/2bw9dzmp
5 C6 | 1 10 µF, 50V | https://www.digikey.com/short/mcj02zrf
6 D2, D3 | 2 1N4001 | https://www.digikey.de/short/vpbrpqr7
7 J2 | 1 Barrel_Jack_Switch_Pin3Ring | https://www.digikey.de/short/bm8m0bnr
8 L1 | 1 330 µH | https://www.reichelt.de/stehende-induktivitaet-09hvp-ferrit-330-h-l-09hvp-330--p255620.html?&nbc=1
9 M1 | 1 CD motor, RF-300F-12350 | Amazon
10 Q1, Q2 | 2 TIP30C | https://www.digikey.com/short/vnqt5f7f
11 R2 | 1 2k2 | generic
12 R3 | 1 270 Ohm | generic
13 R4 | 1 100 Ohm | generic

14 RV1 | 1 1k | https://www.digikey.de/short/23pbq23z
15 SW1 | 1 switch | https://www.digikey.de/short/7zr2m040
16 U7 | 1 AP1117-ADJ | https://www.digikey.de/short/hphdjfzr
17 magnet | 1 magnet, diameter 6mm, thickness 3 mm | Amazon1
18 | screw | 2 M2x6 screw | generic
19 | M2 nuts | 2 M2 nuts | generic
20 bolt | 4 bolt M3x20mm, female - female | https://shop.der-schraubenladen.de/Abstandsbolzen-Distanzhalter-Distin-Innen-Innen-Messing-vernickelt/SW11544.26
21 screw | 7 screw flat head, M3x6 | https://shop.der-schraubenladen.de/schrauben/metrische-schrauben/schrauben-flachkopf/2144/iso-7380-2-linsenschraube-mit-flansch-innensechskant-edelstahl-a2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
22 bumper | 4 bumper lens shape, diam. 6.4 mm, thickness 1.9 mmhttps://amzn.eu/d/7VAHGcK

## 3. PCBs

1 PCB RDpico_display | 1 4 layer PCB | custom made from Gerber files, various sources, for example JLCPCB.com
2 | PCB
| RDpico_motor_tray | 1 2 layer PCB | custom made from Gerber files, various sources, for example JLCPCB.com
3 PCB RDpico_PS | 1 2 layer PCB | custom made from Gerber files, various sources, for example JLCPCB.com
4 PCB Sek_coil V3 | 1 2 layer PCB | custom made from Gerber files, various sources, for example JLCPCB.com
5 PCB tray | 1 2 layer PCB | custom made from Gerber files, various sources, for example JLCPCB.com

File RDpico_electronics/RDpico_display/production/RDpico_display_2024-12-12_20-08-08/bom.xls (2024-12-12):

Designator | Footprint | Quantity | Value | LCSC Part #
J1 | microSD_SMD | 1 | Micro_SD_Card | C5155564
Q1 | SOT-23 | 1 | IRLML6401 | C2835446
Q3 | SOT-23 | 1 | IRLML6401 | C2835446
Q5 | SOT-23 | 1 | IRLML6401 | C2835446
Q7 | SOT-23 | 1 | IRLML6401 | C2835446
Q9 | SOT-23 | 1 | IRLML6401 | C2835446
Q11 | SOT-23 | 1 | IRLML6401 | C2835446
Q13 | SOT-23 | 1 | IRLML6401 | C2835446

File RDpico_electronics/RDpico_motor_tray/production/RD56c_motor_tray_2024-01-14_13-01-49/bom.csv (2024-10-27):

Designator | Footprint | Quantity | Value | LCSC Part #
M1 | motor_tray | 1 | Motor_DC
M2 | motor | 1 | Motor_DC

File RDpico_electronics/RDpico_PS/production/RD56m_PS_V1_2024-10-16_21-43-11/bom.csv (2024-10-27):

Designator | Footprint | Quantity | Value | LCSC Part #
C1 | MKP10_630V | 1 | 33nF
C2 | CP_Radial_D4.0mm_P1.50mm | 1 | 10µ, 50V | C13585
C3 | CP_Radial_D6.3mm_P2.50mm | 1 | 100µ
C4, C5 | C_Rect_L7.0mm_W2.0mm_P5.00mm | 2 | 100nF
C6 | CP_Radial_D4.0mm_P1.50mm | 1 | 10µ
D2, D3 | D_DO-41_SOD81_P10.16mm_Horizontal | 2 | 1N4001
J2 | GRAVITECH_CON-SOCJ-2155 | 1 | Barrel_Jack_Switch_Pin3Ring
L1 | L_vertical12 | 1 | 330µH
M1 | motor_tray | 1 | Motor_DC
Q1, Q2 | TO220_vertikal | 2 | NPN
R2 | R_Axial_DIN0207_L6.3mm_D2.5mm_P10.16mm_Horizontal | 1 | 2k2
R3 | R_Axial_DIN0207_L6.3mm_D2.5mm_P10.16mm_Horizontal | 1 | 120
R4 | R_Axial_DIN0207_L6.3mm_D2.5mm_P10.16mm_Horizontal | 1 | 47
RV1 | Poti_10mm | 1 | 470
SW1 | Switch1 | 1 | SW_DPDT_x2
U1, U2, U3, U4, U5, U6 | Pin_2mm | 6 | Pin-Connector
U7 | SOT-223-3_TabPin2 | 1 | AP1117-ADJ

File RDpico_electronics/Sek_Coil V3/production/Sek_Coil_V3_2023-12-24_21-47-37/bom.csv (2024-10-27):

Designator | Footprint | Quantity | Value | LCSC Part #
L101 | coil_large | 1 | ~

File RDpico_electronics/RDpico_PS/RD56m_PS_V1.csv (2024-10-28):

# | Reference | Qty | Value | Footprint | DNP
1 | C1 | 1 | 33nF | my_footprints:MKP10_630V
2 | C2 | 1 | 10µ, 50V | Capacitor_THT:CP_Radial_D4.0mm_P1.50mm
3 | C3 | 1 | 100µ | Capacitor_THT:CP_Radial_D6.3mm_P2.50mm
4 | C4, C5 | 2 | 100nF | Capacitor_THT:C_Rect_L7.0mm_W2.0mm_P5.00mm
5 | C6 | 1 | 10µ | Capacitor_THT:CP_Radial_D4.0mm_P1.50mm
6 | D2, D3 | 2 | 1N4001 | Diode_THT:D_DO-41_SOD81_P10.16mm_Horizontal
7 | J2 | 1 | Barrel_Jack_Switch_Pin3Ring | my_footprints:GRAVITECH_CON-SOCJ-2155
8 | L1 | 1 | 330µH | my_footprints:L_vertical12
9 | M1 | 1 | Motor_DC | my_footprints:motor_tray
10 | Q1, Q2 | 2 | NPN | my_footprints:TO220_vertikal
11 | R2 | 1 | 2k2 | Resistor_THT:R_Axial_DIN0207_L6.3mm_D2.5mm_P10.16mm_Horizontal
12 | R3 | 1 | 120 | Resistor_THT:R_Axial_DIN0207_L6.3mm_D2.5mm_P10.16mm_Horizontal
13 | R4 | 1 | 47 | Resistor_THT:R_Axial_DIN0207_L6.3mm_D2.5mm_P10.16mm_Horizontal
14 | RV1 | 1 | 470 | my_footprints:Poti_10mm
15 | SW1 | 1 | SW_DPDT_x2 | my_footprints:Switch1
16 | U1, U2, U3, U4, U5, U6 | 6 | Pin-Connector | my_footprints:Pin_2mm
17 | U7 | 1 | AP1117-ADJ | Package_TO_SOT_SMD:SOT-223-3_TabPin2

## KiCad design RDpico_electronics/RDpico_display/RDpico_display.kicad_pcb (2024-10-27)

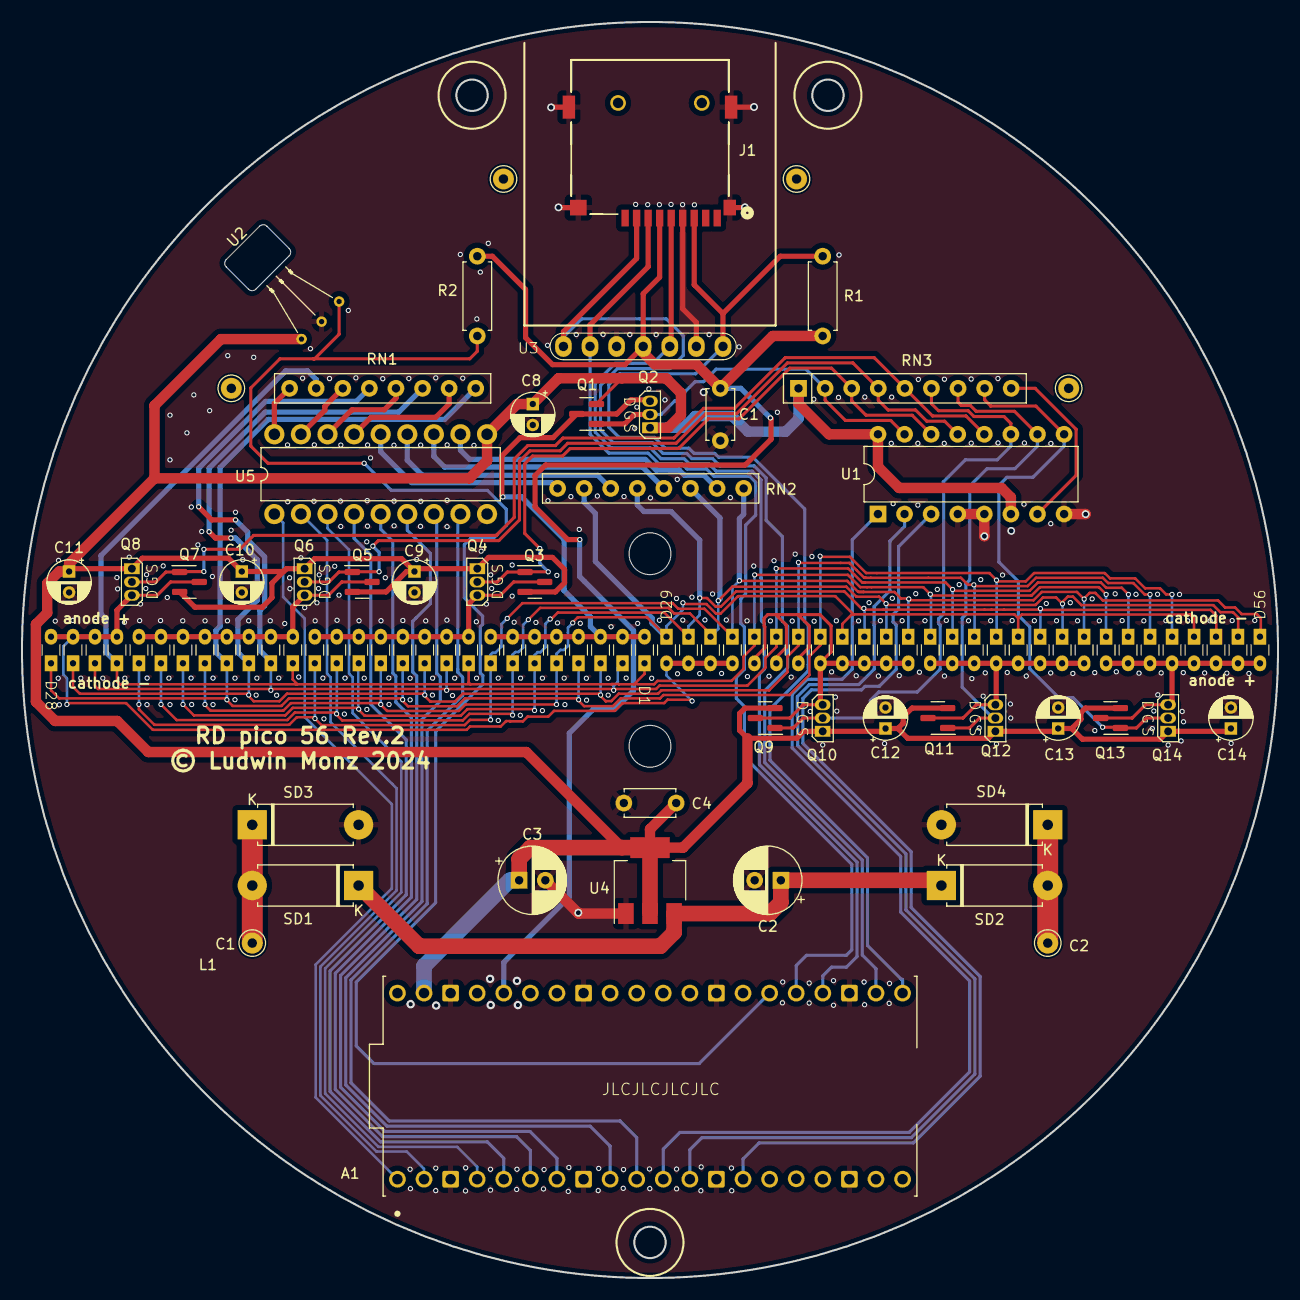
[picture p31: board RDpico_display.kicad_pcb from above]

Board: 4 copper layers, 120.0 x 120.0 mm, 98 parts (0 on the bottom side), 53 nets.

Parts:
A1: SC0918; MODULE_SC0918
C1, C4: 100nF; C_Disc_D4.7mm_W2.5mm_P5.00mm
C2: 220µF; CP_Radial_D6.3mm_P2.50mm
C3: 100µF; CP_Radial_D6.3mm_P2.50mm
C8, C9, C10, C11, C12, C13, C14: 10µ; CP_Radial_D4.0mm_P2.00mm
D1, D2, D3, D4, D5, D6, D7, D8, D9, D10, D11, D12, D13, D14, D15, D16, D17, D18, D19, D20, D21, D22, D23, D24, D25, D26, D27, D28, D29, D30, D31, D32, D33, D34, D35, D36, D37, D38, D39, D40, D41, D42, D43, D44, D45, D46, D47, D48, D49, D50, D51, D52, D53, D54, D55, D56: LED; LED_rect_2x3
J1: Micro_SD_Card; microSD_SMD
L1: Coil; coil_large
Q1, Q3, Q5, Q7, Q9, Q11, Q13: IRLML6401; SOT-23
Q2, Q4, Q6, Q8, Q10, Q12, Q14: BS250; BS250P
R1: 10k; R_Axial_DIN0207_L6.3mm_D2.5mm_P7.62mm_Horizontal
R2: 2.2k; R_Axial_DIN0207_L6.3mm_D2.5mm_P7.62mm_Horizontal
RN1, RN2: 47; RN4
RN3: 47k; R_Array_SIP9
SD1, SD2, SD3, SD4: 1N5818; D_5W_P10.16mm_Horizontal
U1: 74HCT138; DIP-16_W7.62mm
U2: A3144; A3144_front
U3: 7pin
U4: LM1117-5.0; SOT-223-3_TabPin2
U5: ULN2803A

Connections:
+3.3V: A1.36 (3V3_OUT), C1.1, J1.4 (VDD), R1.1, R2.2, U3.4 (VCC)
+5V: A1.39 (VSYS), C3.1, C4.2, C8.1, C9.1, C10.1, C11.1, C12.1, C13.1, C14.1, Q1.2 (S), Q2.3 (S), Q3.2 (S), Q4.3 (S), Q5.2 (S), Q6.3 (S), Q7.2 (S), Q8.3 (S), Q9.2 (S), Q10.3 (S), Q11.2 (S), Q12.3 (S), Q13.2 (S), Q14.3 (S), RN3.1 (common), U1.6 (E2), U1.16 (VCC), U2.1 (Vcc), U4.2 (VO), U5.10 (COM)
GND: A1.3 (GND), A1.8 (GND), A1.13 (GND), A1.18 (GND), A1.23 (GND), A1.28 (GND), A1.33 (AGND), A1.38 (GND), C1.2, C2.2, C3.2, C4.1, C8.2, C9.2, C10.2, C11.2, C12.2, C13.2, C14.2, J1.6 (VSS), J1.10 (S), J1.11 (S), J1.12 (S), J1.13 (S), SD3.2 (A), SD4.2 (A), U1.4 (~E0), U1.5 (~E1), U1.8 (GND), U2.2 (Ground), U3.2 (GND), U3.5 (GND), U4.1 (GND), U5.9 (GND)
LED_c0: D1.1 (K), D9.1 (K), D17.1 (K), D25.1 (K), D33.1 (K), D41.1 (K), D49.1 (K), RN1.2
LED_c1: D2.1 (K), D10.1 (K), D18.1 (K), D26.1 (K), D34.1 (K), D42.1 (K), D50.1 (K), RN1.4
LED_c2: D3.1 (K), D11.1 (K), D19.1 (K), D27.1 (K), D35.1 (K), D43.1 (K), D51.1 (K), RN1.6
LED_c3: D4.1 (K), D12.1 (K), D20.1 (K), D28.1 (K), D36.1 (K), D44.1 (K), D52.1 (K), RN1.8
LED_c4: D5.1 (K), D13.1 (K), D21.1 (K), D29.1 (K), D37.1 (K), D45.1 (K), D53.1 (K), RN2.2
LED_c5: D6.1 (K), D14.1 (K), D22.1 (K), D30.1 (K), D38.1 (K), D46.1 (K), D54.1 (K), RN2.4
LED_c6: D7.1 (K), D15.1 (K), D23.1 (K), D31.1 (K), D39.1 (K), D47.1 (K), D55.1 (K), RN2.6
LED_c7: D8.1 (K), D16.1 (K), D24.1 (K), D32.1 (K), D40.1 (K), D48.1 (K), D56.1 (K), RN2.8
LED_r0: Q1.1 (G), Q2.2 (G), RN3.2 (R1), U1.15 (~Y0)
LED_r1: Q3.1 (G), Q4.2 (G), RN3.3 (R2), U1.14 (~Y1)
LED_r2: Q5.1 (G), Q6.2 (G), RN3.4 (R3), U1.13 (~Y2)
LED_r3: Q7.1 (G), Q8.2 (G), RN3.5 (R4), U1.12 (~Y3)
LED_r4: Q9.1 (G), Q10.2 (G), RN3.6 (R5), U1.11 (~Y4)
LED_r5: Q11.1 (G), Q12.2 (G), RN3.7 (R6), U1.10 (~Y5)
LED_r6: Q13.1 (G), Q14.2 (G), RN3.8 (R7), U1.9 (~Y6)
LED_r7: RN3.9 (R8), U1.7 (~Y7)
unnamed: A1.1 (GP0), U5.1 (I1)
unnamed: A1.2 (GP1), U5.2 (I2)
unnamed: A1.4 (GP2), U5.3 (I3)
unnamed: A1.5 (GP3), U5.4 (I4)
unnamed: A1.6 (GP4), U5.5 (I5)
unnamed: A1.7 (GP5), U5.6 (I6)
unnamed: A1.9 (GP6), U5.7 (I7)
unnamed: A1.10 (GP7), U5.8 (I8)
unnamed: A1.11 (GP8), U1.1 (A0)
unnamed: A1.12 (GP9), U1.2 (A1)
unnamed: A1.14 (GP10), U1.3 (A2)
unnamed: A1.26 (GP20), R2.1, U2.3 (Output)
unnamed: D1.2 (A), D2.2 (A), D3.2 (A), D4.2 (A), D5.2 (A), D6.2 (A), D7.2 (A), D8.2 (A), Q1.3 (D), Q2.1 (D)
unnamed: D9.2 (A), D10.2 (A), D11.2 (A), D12.2 (A), D13.2 (A), D14.2 (A), D15.2 (A), D16.2 (A), Q3.3 (D), Q4.1 (D)
unnamed: D17.2 (A), D18.2 (A), D19.2 (A), D20.2 (A), D21.2 (A), D22.2 (A), D23.2 (A), D24.2 (A), Q5.3 (D), Q6.1 (D)
unnamed: D25.2 (A), D26.2 (A), D27.2 (A), D28.2 (A), D29.2 (A), D30.2 (A), D31.2 (A), D32.2 (A), Q7.3 (D), Q8.1 (D)
unnamed: D33.2 (A), D34.2 (A), D35.2 (A), D36.2 (A), D37.2 (A), D38.2 (A), D39.2 (A), D40.2 (A), Q9.3 (D), Q10.1 (D)
unnamed: D41.2 (A), D42.2 (A), D43.2 (A), D44.2 (A), D45.2 (A), D46.2 (A), D47.2 (A), D48.2 (A), Q11.3 (D), Q12.1 (D)
unnamed: D49.2 (A), D50.2 (A), D51.2 (A), D52.2 (A), D53.2 (A), D54.2 (A), D55.2 (A), D56.2 (A), Q13.3 (D), Q14.1 (D)
unnamed: L1.1, SD1.2 (A), SD3.1 (K)
unnamed: C2.1, SD1.1 (K), SD2.1 (K), U4.3 (VI)
unnamed: L1.2, SD2.2 (A), SD4.1 (K)
unnamed: RN1.1, U5.18 (O1)
unnamed: RN1.3, U5.17 (O2)
unnamed: RN1.5, U5.16 (O3)
unnamed: RN1.7, U5.15 (O4)
unnamed: RN2.1, U5.14 (O5)
unnamed: RN2.3, U5.13 (O6)
unnamed: RN2.5, U5.12 (O7)
unnamed: RN2.7, U5.11 (O8)
SD_CS: A1.22 (GP17), J1.2 (DAT3/CD), U3.7 (CS)
SD_MISO: A1.21 (GP16), J1.7 (DAT0), R1.2, U3.1 (MISO)
SD_MOSI: A1.25 (GP19), J1.3 (CMD), U3.6 (MOSI)
SD_SCK: A1.24 (GP18), J1.5 (CLK), U3.3 (SCK)

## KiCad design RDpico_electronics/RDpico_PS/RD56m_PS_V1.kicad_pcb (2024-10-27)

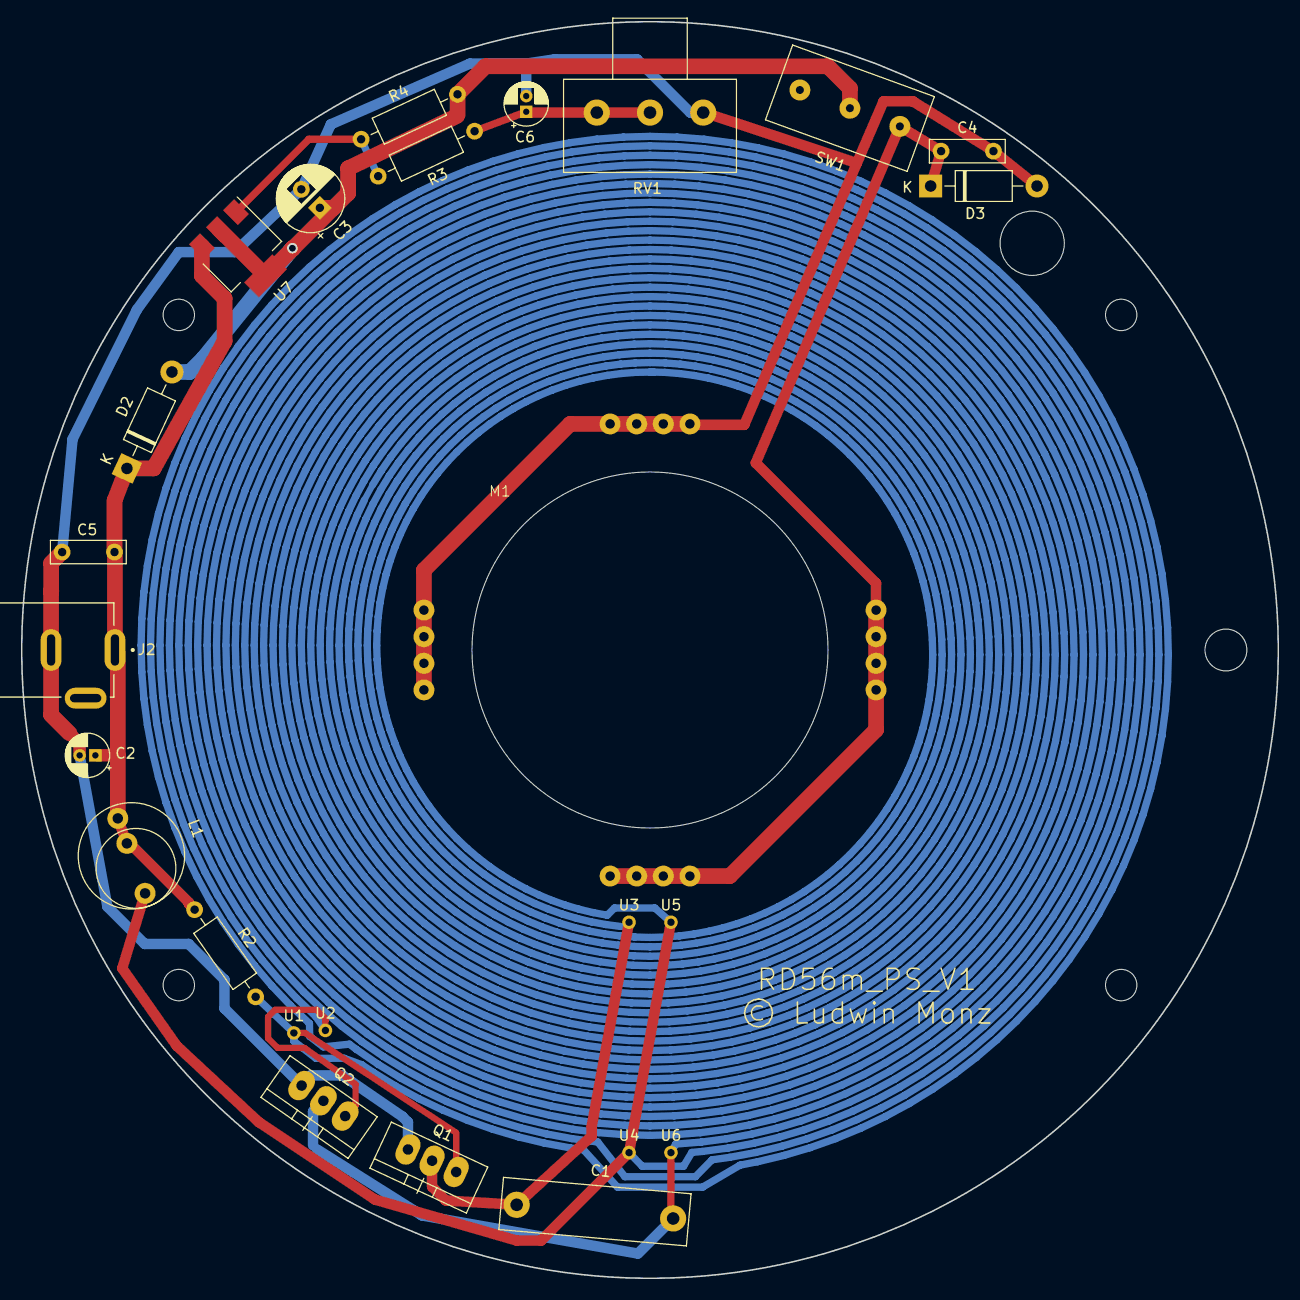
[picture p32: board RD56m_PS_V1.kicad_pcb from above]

Board: 2 copper layers, 120.0 x 120.0 mm, 25 parts (0 on the bottom side), 8 nets.

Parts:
C1: 33nF; MKP10_630V
C2: 10µ, 50V; CP_Radial_D4.0mm_P1.50mm
C3: 100µ; CP_Radial_D6.3mm_P2.50mm
C4, C5: 100nF; C_Rect_L7.0mm_W2.0mm_P5.00mm
C6: 10µ; CP_Radial_D4.0mm_P1.50mm
D2, D3: 1N4001; D_DO-41_SOD81_P10.16mm_Horizontal
J2: Barrel_Jack_Switch_Pin3Ring; GRAVITECH_CON-SOCJ-2155
L1: 330µH; L_vertical12
M1: Motor_DC; motor_tray
Q1, Q2: NPN; TO220_vertikal
R2: 2k2; R_Axial_DIN0207_L6.3mm_D2.5mm_P10.16mm_Horizontal
R3: 120; R_Axial_DIN0207_L6.3mm_D2.5mm_P10.16mm_Horizontal
R4: 47; R_Axial_DIN0207_L6.3mm_D2.5mm_P10.16mm_Horizontal
RV1: 470; Poti_10mm
SW1: SW_DPDT_x2; Switch1
U1, U2, U3, U4, U5, U6: Pin-Connector; Pin_2mm
U7: AP1117-ADJ; SOT-223-3_TabPin2

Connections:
+12V: C2.1, C5.1, D2.1 (K), J2.1, L1.1, L1.3, R2.2, U7.3 (VI)
GND: C2.2, C3.2, C4.2, C5.2, C6.2, D3.2 (A), J2.3, M1.2 (-), Q1.3 (E), Q2.3 (E), RV1.1
unnamed: C6.1, R4.2, RV1.2, RV1.3
unnamed: C3.1, D2.2 (A), R3.1, SW1.2 (B), U7.2 (VO)
unnamed: C4.1, D3.1 (K), M1.1 (+), SW1.3 (C)
unnamed: Q1.1 (B), Q2.1 (B), R2.1, U1.1 (Pin1), U2.1 (Pin1)
unnamed: C1.1, C1.2, L1.2, Q1.2 (C), Q2.2 (C), U3.1 (Pin1), U4.1 (Pin1), U5.1 (Pin1), U6.1 (Pin1)
unnamed: R3.2, R4.1, U7.1 (ADJ)

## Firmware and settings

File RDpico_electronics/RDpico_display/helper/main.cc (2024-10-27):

#include "lib.h"
#include <stdio.h>
#include <cmath>
#include <fstream>

int main() {
    printer("LED data\n");

    std::ofstream f;
    std::string file_name = "/Users/ludwin/Elektronik/RD128/RD128_electronics/RD128_display/helper/output.txt";
    f.open(file_name);

    double LED_circle = 58.5;
    double Via_circle = 55.9;

// LED_col0...LED_col7
// supply of LEDs, 8 circles

    double radial_distance, theta;
    double LED_x, LED_y, Via_x, Via_y, s_start_x, s_start_y, s_end_x, s_end_y;
    std::string text, line1, line2, line3, front, back;
    int LED_nr, rest, net;

    for (LED_nr =0; LED_nr < 128; LED_nr++) {
        radial_distance = 132.825 - LED_nr*2.1;
        theta = radial_distance/60;

        rest = LED_nr%8;
        if (LED_nr>63) rest = 7 - rest;

        if (rest==0) net=3;
        else net=rest+4;

        if (LED_nr<64) {
            front = "\"F.Cu\"";
            back = "\"B.Cu\"";
        }
        else {
            front = "\"B.Cu\"";
            back = "\"F.Cu\"";
        }

        LED_x = - LED_circle * sin(theta);
        LED_y = - LED_circle * cos(theta);
        Via_x = - (Via_circle - 0.6 * rest) * sin(theta);
        Via_y = - (Via_circle - 0.6 * rest) * cos(theta);


        s_start_x = Via_x;
        s_start_y = Via_y;

        text = "LED: " + std::to_string(LED_nr)+"    x via= "+ std::to_string(Via_x)+"   y via= "+std::to_string(Via_y)+"\n";
        line1 ="(segment (start "+std::to_string(LED_x)+" "+std::to_string(LED_y)+") (end "+std::to_string(Via_x)+" "+std::to_string(Via_y)+") (width 0.2) (layer "+front+") (net "+std::to_string(net)+") (tstamp c98c8beb-da98-4656-8da4-32e4cf1c68d6))\n";
        line2 ="(via (at "+std::to_string(Via_x)+" "+std::to_string(Via_y)+") (size 0.5) (drill 0.3) (layers \"F.Cu\" \"B.Cu\") (net "+std::to_string(net)+")(tstamp c98c8beb-da98-4656-8da4-32e4cf1c68d6))\n";

        printer (line1);
        printer (line2);
        f<<line1;
        f<<line2;

        int i_max=17;
        if ((LED_nr>55)&&(LED_nr<64)) {
            i_max=4*(8-rest)-1;
        }

        for (int i = 1; i<i_max; i++) {
            s_end_x = - (Via_circle - 0.6 * rest) * sin(theta-i*0.0175);
            s_end_y = - (Via_circle - 0.6 * rest) * cos(theta-i*0.0175);

            line3 = "(segment (start "+std::to_string(s_start_x)+" "+std::to_string(s_start_y)+") (end "+std::to_string(s_end_x)+" "+std::to_string(s_end_y)+") (width 0.2) (layer "+back+") (net "+std::to_string(net)+")(tstamp c98c8beb-da98-4656-8da4-32e4cf1c68d6))\n";
            printer (line3);
            f<<line3;
            s_start_x = s_end_x;
            s_start_y = s_end_y;
        }

        if (LED_nr<8) {
            s_start_x = Via_x;
            s_start_y = Via_y;
            for (int i = 1; i<32; i++) {
                s_end_x = - (Via_circle - 0.6 * rest) * sin(theta+i*0.0175);
                s_end_y = - (Via_circle - 0.6 * rest) * cos(theta+i*0.0175);

                line3 = "(segment (start "+std::to_string(s_start_x)+" "+std::to_string(s_start_y)+") (end "+std::to_string(s_end_x)+" "+std::to_string(s_end_y)+") (width 0.2) (layer "+back+") (net "+std::to_string(net)+")(tstamp c98c8beb-da98-4656-8da4-32e4cf1c68d6))\n";
                printer (line3);
                f<<line3;
                s_start_x = s_end_x;
                s_start_y = s_end_y;
            }
        }

    }

// Ground, +5V circle

    double theta1, C_ground_circle, C_5V_circle, C_group_circle;
    theta1 = 132.825/60;
    C_ground_circle = 50.8;
    C_5V_circle = 48;

    s_start_x = -C_ground_circle * sin(theta1);
    s_start_y = -C_ground_circle * cos(theta1);

    for (int i = 1; i<257; i++) {
        s_end_x = -C_ground_circle * sin(theta1-i*0.0175);
        s_end_y = -C_ground_circle * cos(theta1-i*0.0175);
            line3 = "(segment (start "+std::to_string(s_start_x)+" "+std::to_string(s_start_y)+") (end "+std::to_string(s_end_x)+" "+std::to_string(s_end_y)+") (width 0.6) (layer \"F.Cu\") (net 2)(tstamp c98c8beb-da98-4656-8da4-32e4cf1c68d6))\n";
            printer (line3);
            f<<line3;
            s_start_x = s_end_x;
            s_start_y = s_end_y;
    }


    s_start_x = -C_5V_circle * sin(theta1);
    s_start_y = -C_5V_circle * cos(theta1);

    for (int i = 1; i<257; i++) {
        s_end_x = -C_5V_circle * sin(theta1-i*0.0175);
        s_end_y = -C_5V_circle * cos(theta1-i*0.0175);
            line3 = "(segment (start "+std::to_string(s_start_x)+" "+std::to_string(s_start_y)+") (end "+std::to_string(s_end_x)+" "+std::to_string(s_end_y)+") (width 0.75) (layer \"B.Cu\") (net 1)(tstamp c98c8beb-da98-4656-8da4-32e4cf1c68d6))\n";
            printer (line3);
            f<<line3;
            s_start_x = s_end_x;
            s_start_y = s_end_y;
    }


//////////
// C_group circles (4x4 lines each)

    C_group_circle = 46.5;
    for (int line=0; line<4; line++){
        s_start_x = -(C_group_circle-line*0.6) * sin(theta1);
        s_start_y = -(C_group_circle-line*0.6) * cos(theta1);

        int i_max;
        i_max = 2 + line * 16;

        for (int i = 1; i<i_max; i++) {
            s_end_x = -(C_group_circle-line*0.6) * sin(theta1-i*0.0175);
            s_end_y = -(C_group_circle-line*0.6) * cos(theta1-i*0.0175);
                line3 = "(segment (start "+std::to_string(s_start_x)+" "+std::to_string(s_start_y)+") (end "+std::to_string(s_end_x)+" "+std::to_string(s_end_y)+") (width 0.2) (layer \"F.Cu\") (net "+std::to_string(line+27)+")(tstamp c98c8beb-da98-4656-8da4-32e4cf1c68d6))\n";
                printer (line3);
                f<<line3;
                s_start_x = s_end_x;
                s_start_y = s_end_y;
        }
    }

    for (int line=0; line<4; line++){
        s_start_x = -(C_group_circle-line*0.6) * sin(theta1);
        s_start_y = -(C_group_circle-line*0.6) * cos(theta1);

        int i_max;
        i_max = 66 + line * 16;

        for (int i = 1; i<i_max; i++) {
            s_end_x = -(C_group_circle-line*0.6) * sin(theta1-i*0.0175);
            s_end_y = -(C_group_circle-line*0.6) * cos(theta1-i*0.0175);
                line3 = "(segment (start "+std::to_string(s_start_x)+" "+std::to_string(s_start_y)+") (end "+std::to_string(s_end_x)+" "+std::to_string(s_end_y)+") (width 0.2) (layer \"B.Cu\") (net "+std::to_string(line+31)+")(tstamp c98c8beb-da98-4656-8da4-32e4cf1c68d6))\n";
                printer (line3);
                f<<line3;
                s_start_x = s_end_x;
                s_start_y = s_end_y;
        }
    }

    theta1 = -133.875/60;

    for (int line=0; line<4; line++){
        s_start_x = -(C_group_circle-line*0.6) * sin(theta1);
        s_start_y = -(C_group_circle-line*0.6) * cos(theta1);

        int i_max;
        i_max = 2 + line * 16;

        for (int i = 1; i<i_max; i++) {
            s_end_x = -(C_group_circle-line*0.6) * sin(theta1+i*0.0175);
            s_end_y = -(C_group_circle-line*0.6) * cos(theta1+i*0.0175);
                line3 = "(segment (start "+std::to_string(s_start_x)+" "+std::to_string(s_start_y)+") (end "+std::to_string(s_end_x)+" "+std::to_string(s_end_y)+") (width 0.2) (layer \"F.Cu\") (net "+std::to_string(line+43)+")(tstamp c98c8beb-da98-4656-8da4-32e4cf1c68d6))\n";
                printer (line3);
                f<<line3;
                s_start_x = s_end_x;
                s_start_y = s_end_y;
        }
    }

    for (int line=0; line<4; line++){
        s_start_x = -(C_group_circle-line*0.6) * sin(theta1);
        s_start_y = -(C_group_circle-line*0.6) * cos(theta1);

        int i_max;
        i_max = 66 + line * 16;

        for (int i = 1; i<i_max; i++) {
            s_end_x = -(C_group_circle-line*0.6) * sin(theta1+i*0.0175);
            s_end_y = -(C_group_circle-line*0.6) * cos(theta1+i*0.0175);
                line3 = "(segment (start "+std::to_string(s_start_x)+" "+std::to_string(s_start_y)+") (end "+std::to_string(s_end_x)+" "+std::to_string(s_end_y)+") (width 0.2) (layer \"B.Cu\") (net "+std::to_string(line+47)+")(tstamp c98c8beb-da98-4656-8da4-32e4cf1c68d6))\n";
                printer (line3);
                f<<line3;
                s_start_x = s_end_x;
                s_start_y = s_end_y;
        }
    }



    f.close();

    return 0;
}

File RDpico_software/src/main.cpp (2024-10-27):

// =========================================================================================================================================
//                                                 Rotating Display RD56m
//                                                    © Ludwin Monz
// License: Creative Commons Attribution - Non-Commercial - Share Alike (CC BY-NC-SA)
// you may use, adapt, share. If you share, "share alike".
// you may not use this software for commercial purposes 
// =========================================================================================================================================

#include <Arduino.h>
#include "FlashFS.h"
#include "my_RP.h"
#include "webInterface.h"
#include "my_BMP.h"
#include "LED_control.h"
#include "RD_56m.h"

#include <WiFi.h>
#include <time.h>


// =========================================================================================================================================
// 
//                                                        Rotating Display
//
// The program uses OOP in order to structure data and functions. These are the classes:
//
// 1. my_RP
//    description:    the class manages the resources of the RP pico microcontroller. 
//    key methods:    begin()                                         configures Wifi, i2c interface, sets time 
//                    getMyTime()                                     occupies the time and date attributes (see below) 
//                    myPassword()                                    returns Wifi Password which is being used
//                    mySSID()                                        returns Wifi SSID
//    key attributes: int Sec, int Min, int Hour, ...
//
// 2. RD_56
//    description:    the class provides the rotating display object. It loads the image for display, performs the 
//                    transformation from Cartesian to polar coordinates, and updates the display data field. 
//
//    key methods:    begin()                                         initialize display mode and data transfer to the display controller
//                    upload()                                        uploads display data to the display controller
//                    displayBMP(unsigned char bmp[][14])             displays bitmap
//    key attributes: clockMode, brightness
//
// 3. my_BMP
//    description:    this class generates bitmaps for the display. It provides methods for generating clock and weather screens, 
//                    as well as printing text on bitmaps. The bitmap shall be handed over to the RD56 object. 
//    key methods:    generateBMP(int mode, tm* tm, String* ssid)     generates bitmap according to mode, time, ssid
//    key attributes: bitmap[][]                                      this is a 110x110 pixel bitmap
//
// 4. webInterface
//    description:    the class manages the web user interface. It uses the AsyncWebServer library and runs in the background without any need for
//                    attention. The class provides certain attributes, which are set by the web interface:
//    key methods:    begin(String* ssid_)                            starts AsyncWebServer. ssid is displayed (not changed) in web interface
//    key attributes: int clockMode;                                  mode 0 = IP-address, mode 1 = analog clock, mode 2 = digital clock, mode 3 = logo clock, mode 4 = weather clock
//                    int brightness;                                 brightness value in %
//                    char apiKey[50]="";                             apiKey for openweathermap.org
//                    char location[50]="";                           location for openweathermap.org
//                    char country[20]="";                            country for openweathermap.org
//
//
// =========================================================================================================================================

LED_control LEDcontrol;                                 // instance of the LED_control object

my_RP myRP;                                                  // create instance of my_RP
long lastUpdate=0;                                           // remember the time stamp of last display update
int prevSec=0;

webInterface wi56;                                      // create instance of webInterface

long lastWeather;                                            // remember time of last weather updte
my_BMP myBMP;                                                // create instance of my_BMP


RD_56m RD56m;                                                // create instance of RD_56

int right = 0;


// =========================================================================================================================

void setup(){

  // Serial port for debugging purposes
  Serial.begin(115200);

  delay(1000);

  Serial.println("start ............");

  myRP.begin();                             // initiates Wifi, time
  String myssid = myRP.ssid;                // withdraw SSID
  String myIpAddress = myRP.ipAddress;
  
  
  wi56.begin(myssid);                       // start web server

  myRP.getMyTime();
  Serial.printf("Zeit: %d:%d:%d\n", myRP.Hour, myRP.Min, myRP.Sec);

  RD56m.begin();                             // initiate RD56 object
}

void setup1() {
  LEDcontrol.begin();
}

void loop() {
// +++++++++++++++++++++++++++++++++++++++++++++++++++++++++++++++++++++++++++++++++++++++++++++++++
// 
//


  if ( (((millis()-lastWeather)>60000)&&(wi56.clockMode==4)) || wi56.updateWeather) {     // update weather every 60 seconds OR if update requested with update_weather
    lastWeather=millis();
    Serial.println("request weather data.....");
    myBMP.getWeather(wi56.apiKey, wi56.location);
    wi56.updateWI(myBMP.w_icon, myBMP.w_temp, myBMP.w_humi);              // send updated data to webInterface

    wi56.updateWeather=false;
  }

  myRP.getMyTime();
  if (myRP.Sec!=prevSec) {
    prevSec = myRP.Sec;
    Serial.printf("%d:%d:%d   %d.%d.%d\n", myRP.Hour, myRP.Min, myRP.Sec, myRP.Mday, myRP.Mon, myRP.Year );
  }

  long stamp = millis();                                           // current time
  if ((stamp-lastUpdate)>100) {
    lastUpdate = stamp;
    tm* mytm = &myRP.tm1;                                          // myRP holds time
    myBMP.generateBMP(wi56.clockMode, mytm, myRP.ssid.c_str(), myRP.ipAddress.c_str());  // generate bitmap

    unsigned char (*mybitmap)[165] = myBMP.bitmap;                 // pointer at bitmap array
    Serial.print("+");
    RD56m.displayBMP(mybitmap);                                 // update display data according to bitmap
  }

  wi56.update();
}

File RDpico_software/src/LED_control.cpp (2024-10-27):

// =========================================================================================================================================
//                                                 Rotating Display RD56m
//                                                    © Ludwin Monz
// License: Creative Commons Attribution - Non-Commercial - Share Alike (CC BY-NC-SA)
// you may use, adapt, share. If you share, "share alike".
// you may not use this software for commercial purposes 
// =========================================================================================================================================

#include "LED_control.h"
#include <Arduino.h>


// Definition of static variables
long LED_control::_tpt = 0;
long LED_control::_LPT = lpt;
unsigned int LED_control::_line_period = 30000;
int LED_control::_line_counter0 = 120;
int LED_control::_line_counter1 = 0;
int LED_control::_line_offset = lineOffset;

PIO LED_control::pio = pio0;
uint LED_control::sm = 0;

uint8_t LED_control::line[1681][7];			        // 240 lines, 7 sublines, 7x8=56 bits
uint8_t LED_control::line_past[1681][7];             // line_past holds the data for the interlaced pixels	
uint32_t LED_control::subline[7][4];                        // subline data to be pushed to the LEDs

uint32_t LED_control::brightness = 1;

uint8_t LED_control::sublineCount=0;

unsigned int LED_control ::line_period;

// =========================================================================================================================================
//                                                      Constructor
// =========================================================================================================================================

LED_control::LED_control() {
}

// =========================================================================================================================================
//                                                      begin Method
// =========================================================================================================================================

void LED_control::begin() {
    _initMultiplexer();
//    _initTestOutput();
    _initHallIRQ();
    _initPixelIRQ();
}

void LED_control::_initTestOutput() {
    for (int pin=0; pin<16; pin++) {
        gpio_init(pin);										// set gpio as output
	    gpio_set_dir(pin, GPIO_OUT);								//
    }
}

void LED_control::_setTestOutput(bool status) {
    for (int pin=0; pin<8; pin++) gpio_put(pin, status);
    gpio_put(8,1);
    for (int pin=9; pin<16; pin++) gpio_put(pin,0);
}

void LED_control::_initMultiplexer(){

    // Load LED_MUX into this PIO's instruction memory.
 //   uint offset = pio_add_program(pio, &LED_MUX_program);
    uint offset = pio_add_program(pio, &LED_multiplexer_program);

    // initiate confic structures c
//    pio_sm_config c = LED_MUX_program_get_default_config(offset);
    pio_sm_config c = LED_multiplexer_program_get_default_config(offset);

    // Map the state machine's OUT pin group to pins 0, ..., 15
//    sm_config_set_out_pins(&c, 0, 16);
    sm_config_set_out_pins(&c, 0, 8);
    // map the SET pins to pin 15
//    sm_config_set_set_pins(&c, 15, 1);
    sm_config_set_set_pins(&c, 8, 3);
    // define status
    sm_config_set_mov_status (&c, STATUS_TX_LESSTHAN , 1 );   
    // Join TX FIFO
    sm_config_set_fifo_join	(&c, PIO_FIFO_JOIN_TX);	
    // Set pindir for all pins
    pio_sm_set_consecutive_pindirs(pio, sm, 0, 16, true);
    // set clk frequency to 130/50 MHz = 2.6 MHz. 31 wait cycles will correspond to 124 µs => works with "4"
    sm_config_set_clkdiv_int_frac(&c, 100, 0);  // 7 for LED_MUX

    // enable IRQ by setting IRQ0_INTE - interrupt enable register    pis_interrupt0 = PIO_INTR_SM0_LSB
    // this routes the PIO SM interrupts (IRQ0...IRQ7) to the system interrupts 7 and 8.
    pio_set_irq0_source_enabled(pio, pis_interrupt0 , true);
    //Set the handler in the NVIC. IRQ7 = PIO0_IRQ_0
    irq_set_exclusive_handler(7, _pioIRQ);  
    //enabling the PIO0_IRQ_0
    irq_set_enabled(7, true);   

    // Set this pin's GPIO function "pio"
    for (uint i=0; i<16; i++) pio_gpio_init(pio, i);

    // Load configuration to pio, and jump to the start of the program
    pio_sm_init(pio, sm, offset, &c);

    // Set the state machine running
    pio_sm_set_enabled(pio, sm, true);
}

void LED_control::_pioIRQ() {
    if (sublineCount<7) {
        pio_sm_put(pio, sm, subline[sublineCount][0]);       // push one full line to the pio
        pio_sm_put(pio, sm, subline[sublineCount][1]);  
//        pio_sm_put(pio, sm, subline[sublineCount][2]);  
//        pio_sm_put(pio, sm, subline[sublineCount][3]); 
        sublineCount++;
    }
    pio_interrupt_clear(pio, 0);                               // clear interrupt
}

void LED_control::_initHallIRQ() {
    gpio_init(Hall);
    gpio_set_dir(Hall, GPIO_IN);
    gpio_set_function(Hall, GPIO_FUNC_SIO);								// software IO control (SIO)

	gpio_set_irq_enabled_with_callback(Hall, GPIO_IRQ_EDGE_FALL, true, &_HallIRQ);    // attach HallRIQ

    pwm_clear_irq(0);										// clear pwm interrupt
	pwm_set_irq_enabled(0, true);							// enable pwm interrupt

} 

void LED_control::_HallIRQ(uint gpio, uint32_t events) {
    _tpt = _tpt + pwm_get_counter(0);

	long new_line_period = _tpt/_LPT;

	if (new_line_period>65500) new_line_period = 65500;

    long delta = labs(new_line_period - _line_period);
    if(delta<10) _line_period = (63*_line_period+new_line_period)/64;      // Otherwise make small corrections, only.
  	if((delta>=10)&&(delta<100)) _line_period = (15*_line_period+new_line_period)/16;
    if(delta>=100) _line_period = new_line_period;
    
  	pwm_set_wrap (0, _line_period);							      // upper threshold of counter 0

 	_tpt = 0;
  	_line_counter1 = _line_offset;  							  // restart line_counter
  	_line_counter0 = _line_offset + _LPT/2;

  	if (_line_counter0 >= _LPT) _line_counter0 = _line_counter0-_LPT;

}

void LED_control::_initPixelIRQ() {
    gpio_init(PWM0_A);										// set gpio as output
	gpio_set_dir(PWM0_A, true);								//

	gpio_set_function(PWM0_A, GPIO_FUNC_PWM);				// enable PWM pin

	pwm_set_wrap (0, _line_period);							// upper threshold of counter 0
	pwm_set_phase_correct (0, false);						// counter 0 will reset to 0, once upper threshold is reached
	
	pwm_set_clkdiv_int_frac(0, 2, 0);					    // set divisor for clock divider (system clock = 125 MHz)

	pwm_set_chan_level(0, 0, _line_period-1);			    // level is the mid threshold, when the output goes to zero

	pwm_set_enabled (0, true);								// enable PWM slice 0 (output pins 16 and 17)

	irq_set_exclusive_handler(PWM_IRQ_WRAP, _PixelIRQ);		// attach PixelIRQ() to the PWM interrupt
	irq_set_enabled(PWM_IRQ_WRAP, true);					// enanble irq

	_startPattern();
}
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

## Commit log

2024-10-28 BOM added
    [BOM.xlsx]
2024-10-28 BOM completed
    [BOM.xlsx, RD56m_PS_V1.csv, RD56m_PS_V1.kicad_sch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]
2024-12-12 update production files
    [LED1.kicad_sch, bom.csv, bom.xls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]

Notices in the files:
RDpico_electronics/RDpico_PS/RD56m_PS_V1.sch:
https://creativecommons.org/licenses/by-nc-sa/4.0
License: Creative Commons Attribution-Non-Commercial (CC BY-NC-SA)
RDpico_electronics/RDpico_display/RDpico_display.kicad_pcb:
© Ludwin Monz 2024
